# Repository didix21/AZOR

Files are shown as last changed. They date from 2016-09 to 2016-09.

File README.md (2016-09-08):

# AZOR
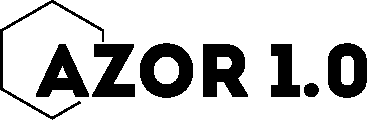
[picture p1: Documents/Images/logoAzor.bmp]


This repository contains all the AZOR 1.0 board KiCad files.  

## About Hardware 

AZOR 1.0 is based on [DUET 0.85](http://reprap.org/wiki/Duet#Drive_numbers) created by [dc42](https://github.com/dc42). I have done very important modifications as delete Ethernet and micro SD ports. Instead, I have added a USB 2.0 port to read USB Sticks. 

Moreover, the integrated steppers A4982 have been deleted and instead of that, I have placed HEADER PINS to connect drivers as A4988 or DRV8825. 

## About Software 

AZOR 1.0 use [Marlin4AZOR](https://github.com/didix21/Marlin4AZOR), it is a modified version of work  done by [Wurstnase](https://github.com/Wurstnase). In other words it is based on [Marlin4Due](https://github.com/Wurstnase/Marlin4Due).

## Main Features

- MCU: 32-bits, ATSAM3X8E-AU.
- Port Expansion
- Support for drivers: A4982 and DRV8825.
- Two FAN PWM ports.
- PTS-Panel Header Pin port.
- SD Header Pin Port.
- USB 2.0 port.

## License

Marlin is published under the [GPL license](LICENSE).

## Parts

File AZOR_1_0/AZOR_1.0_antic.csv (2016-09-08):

Id | Designator | Package | Quantity | Designation | Supplier and ref | Description
1 | U8,U11,U6,U5,U7 | DRV8825 | 10 | DRV8825_ | SSW-108-01-G-S | 2.54mm 8 Way 1 Row Straight PCB Socket Through Hole Board to Board
2 | U1 | LQFP144 | 1 | ATSAM3X8E | Atmel: ATSAM3X8EA-AU | Atmel ATSAM3X8EA-AU, 32bit ARM Cortex M3 Microcontroller, 84MHz, 16 kB, 2 x 256 kB Flash, ROM, 144-Pin LQFP
3 | TR3,TR1,TR7,TR6 | SOT-23 | 4 | BSH105 | BSH105,215 | NXP BSH105,215 N-channel MOSFET Transistor, 1.05 A, 20 V, 3-Pin TO-236AB
4 | C61,C68,C66,C59 | C_0805 | 4 | 4u7 | C0805C475K9PACTU | Kemet 0805 4.7?F Ceramic Multilayer Capacitor, 6.3V dc, 85°C, X5R Dielectric, ±10% SMD
5 | J22 | uUSB_new | 1 | USB | DX4R005H91 | SMT Type B Version 2.0 Micro USB Connector Socket, 100 V ac, 1.8A
6 | J23 | TERM_2-WAY_6.35mm | 1 | POWER IN | 1714955 | MKDS 5/2-6,35 2way 6.35mm terminal block
7 | TR5,TR9 | SOT-23 | 2 | PMV40UN2 | PMV40UN,215 | NXP PMV40UN,215 N-channel MOSFET Transistor, 4.9 A, 30 V, 3-Pin TO-236AB
8 | U2 | SOT-223 | 1 | TC2117-3.3VDBTR | TC2117-3.3VDBTR | Microchip TC2117-3.3VDBTR, LDO Voltage Regulator, 800mA, 3.3 V ±0.5%, 2.7 ? 6 Vin, 3-Pin SOT-223
9 | C23,C33,C32,C22,C3,C92,C94,C99,C102,C113 | C_ELEC_6.3x7.7 | 10 | 100u | EEEFTH101XAP | 100?F 50 V dc Aluminium Electrolytic Capacitor D8, FT SMD Series 2000h 6.3 Dia. x 7.7mm
10 | R18,R22,R60,R79 | R_0603 | 4 | 470R | CR0603-JW-471ELF | Bourns CR0603 Series Thick Film Surface Mount Resistor 0603 Case 470? ±5% 0.1W ±200ppm/°C
11 | R20,R23,R97 | R_0603 | 3 | 220R | CRG0603F220R | Thick Film Surface Mount Fixed Resistor 0603 Case 220? ±1% 0.1W ±100ppm/°C
12 | R57,R56,R58,R59 | R_0603 | 4 | 100R | CR0603-FX-1000ELF | Thick Film Surface Mount Fixed Resistor 0603 Case 100? ±1% 0.1W ±100ppm/°C
13 | R1 | R_0603 | 1 | 3K3 | CR0603-FX-3301ELF | Thick Film Surface Mount Fixed Resistor 0603 Case 3.3k? ±1% 0.1W ±100ppm/°C
14 | R2,R3 | R_0603 | 2 | 39R 1% | ERJ3RED39R0V | Thick Film Surface Mount Resistor 0603 Case 39? ±0.5% 0.1W ±100ppm/°C
15 | R24,R81,R80,R99,R82 | R_0603 | 5 | 10K | CR0603-FX-1002ELF | CR0603-FX Series Thick Film Surface Mount Fixed Resistor 0603 Case 10k? ±1% 0.1W ±100ppm/°C
16 | R25,R77,R78 | R_0603 | 3 | 100k | CR0603-FX-1003HLF | CR0603-FX Series Thick Film Surface Mount Fixed Resistor 0603 Case 100k? ±1% 0.1W ±100ppm/°C
17 | C40,C41,C42,C43,C70,C46,C48,C49,C72,C71,C69,C50,C67,C51,C64,C62,C52,C60,C91,C93,C112,C5 | C_0603 | 22 | 0u1 | C0603C105K8PACTU | Kemet 0603 C 1uF Ceramic Multilayer Capacitor, 10 V dc, +85°C, X5R Dielectric, ±10%
18 | R38,R40,R28,R26,R89 | R_0603 | 5 | 10k | CR0603-FX-1002ELF | CR0603-FX Series Thick Film Surface Mount Fixed Resistor 0603 Case 10k? ±1% 0.1W ±100ppm/°C
19 | R48 | R_0603 | 1 | 6k8 | ERA3AEB682V | Panasonic ERA Series Thin Film Surface Mount Resistor 0603 Case 6.8k? ±0.1% 0.1W ±25ppm/°C
20 | D3 | D_0603 | 1 | USB | LA L296-P2R1-1 | Opto LO L296-P2R1-24 Orange LED, 606 nm 0603, Rectangle Lens SMD Package
21 | C4,C18,C19,C47,C98,C97,C53 | C_0805 | 7 | 10u | C0805C106K4PACTU | Kemet 0805 C 10?F Ceramic Multilayer Capacitor, 16 V dc, +85°C, X5R Dielectric, ±10%
22 | TR4,TR2,TR8 | D-PAK | 3 | IPD036N04L | IPD036N04LG | Infineon IPD036N04LG N-channel MOSFET Transistor, 90 A, 40 V, 3-Pin TO-252
23 | R67,R68,R65,R55,R100,R98 | R_0603 | 6 | 4k7 | CR0603-FX-1000ELF | Bourns CR0603-FX Series Thick Film Surface Mount Fixed Resistor 0603 Case 100? ±1% 0.1W ±100ppm/°C
24 | D8 | D_0603 | 1 | FAN0 | LA L296-P2R1-1 | Opto LO L296-P2R1-24 Orange LED, 606 nm 0603, Rectangle Lens SMD Package
25 | D7 | D_0603 | 1 | E0 Heat | LP L296-J2L2-25 | Osram Opto LP L296-J2L2-25 Green LED, 560 nm 0603, Rectangle Lens SMD Package
26 | D6 | D_0603 | 1 | Bed Heat | LP L296-J2L2-25 | Osram Opto LP L296-J2L2-25 Green LED, 560 nm 0603, Rectangle Lens SMD Package
27 | J5 | PIN_ARRAY_2X1 | 1 | BED TEMP | 790-1098 | 2 way PCB terminal block 2.54mm
28 | R69,R70,R72 | R_0603 | 3 | 680R | CRCW0603680RFKEA | Vishay CRCW Series Thick Film Surface Mount Resistor 0603 Case 680? ±1% 0.1W ±100ppm/°C
29 | D9 | D_0603 | 1 | Y Stop | LO L296-P2R1-24 | Opto LO L296-P2R1-24 Orange LED, 606 nm 0603, Rectangle Lens SMD Package
30 | D10 | D_0603 | 1 | Z Stop | LO L296-P2R1-24 | Opto LO L296-P2R1-24 Orange LED, 606 nm 0603, Rectangle Lens SMD Package
31 | D12 | D_0603 | 1 | X Stop | LO L296-P2R1-24 | Opto LO L296-P2R1-24 Orange LED, 606 nm 0603, Rectangle Lens SMD Package
32 | D13,D14 | uSMA | 2 | SS14M | SS14 | Fairchild SS14, SMT Schottky Diode, 40V 1A, 2-Pin DO-214AC
33 | R21,R19,R53 | R_0603 | 3 | 4K7 | CR0603-FX-1000ELF | Bourns CR0603-FX Series Thick Film Surface Mount Fixed Resistor 0603 Case 100? ±1% 0.1W ±100ppm/°C
34 | L6,L5,L4,L3,L7 | R_0603 | 5 | 100Mhz | 3613C1R0K | Series Shielded Wire-wound SMD Inductor with a Ferrite Core, 1uH ±10% 450mA
35 | C13,C95 | C_0603 | 2 | 1u | C0603C105K4PACTU | Kemet 0603 C 1?F Ceramic Multilayer Capacitor, 16 V dc, +85°C, X5R Dielectric, ±10%
36 | C44,C45,C65 | C_0603 | 3 | 10p | C0603C100J5GACTU | Kemet 0603 10pF Ceramic Multilayer Capacitor, 50V dc, 125°C, C0G Dielectric, ±5% SMD
37 | C2 | C_0603 | 1 | 0u01 | C0603C100J5GACTU | Kemet 0603 10pF Ceramic Multilayer Capacitor, 50V dc, 125°C, C0G Dielectric, ±5% SMD
38 | R54 | R_0603 | 1 | 2k7 | CR0603-FX-1000ELF | Bourns CR0603-FX Series Thick Film Surface Mount Fixed Resistor 0603 Case 100? ±1% 0.1W ±100ppm/°C
39 | R61 | R_0603 | 1 | 2K15 | CRCW06032K15FKEA | Vishay CRCW Series Thick Film Surface Mount Resistor 0603 Case 2.15k? ±1% 0.1W ±100ppm/°C
40 | D1,D2 | DO-220AA | 2 | SS3P4 | SS3P4-M3/84A | Vishay SS3P4-M3/84A, SMT Schottky Diode, 40V 3A, 2-Pin SMP
41 | X2 | Xtal_5x3.2 | 1 | CRYSTAL_4PIN |  | 12MHz KX-7 20pF, CRYSTAL -3.2-2.5
42 | JP9 | JUMPER | 1 | 5V_EN | W81102T3825RC | RS Pro, 2.54mm Pitch 2 Way 1 Row Straight PCB Header, Solder Termination
43 | JP10 | JUMPER | 1 | ATX_5V_EN | W81102T3825RC | RS Pro, 2.54mm Pitch 2 Way 1 Row Straight PCB Header, Solder Termination
44 | J27,J26 | TP | 2 | GND | 68000-401HLF | Amphenol FCI BergStik Series, Series Number 68000, 2.54mm Pitch 1 Way 1 Row Straight Header, Through Hole Termination
45 | D16 | D_0603 | 1 | 3.3V | LP L296-J2L2-25 | Osram Opto LP L296-J2L2-25 Green LED, 560 nm 0603, Rectangle Lens SMD Package
46 | D17 | D_0603 | 1 | 5V+ | LP L296-J2L2-25 | Osram Opto LP L296-J2L2-25 Green LED, 560 nm 0603, Rectangle Lens SMD Package
47 | D15 | D_0603 | 1 | VIN | LP L296-J2L2-25 | Osram Opto LP L296-J2L2-25 Green LED, 560 nm 0603, Rectangle Lens SMD Package
48 | C90 | C_0603 | 1 | 10nF | C0603C103K5RACTU | Kemet 0603 10nF Ceramic Multilayer Capacitor, 50V dc, 125°C, X7R Dielectric, ±10% SMD
49 | J4 | TERM_2-WAY_6.35mm | 1 | BED HEAT | 1714955 | MKDS 5/2-6,35 2way 6.35mm terminal block
50 | ,, | Fixing_M3 | 3
51 | R86,R85 | R_1206 | 2 | 0R1 | ERJ8BWFR100V | Panasonic ERJ8BW Series Thick Film Low Ohmic Surface Mount Resistor 1206 Case 100m? ±1% 1W ±100ppm/°C
52 | R88 | R_0603 | 1 | 750R | CRCW0603750RFKEA | Vishay CRCW Series Thick Film Surface Mount Resistor 0603 Case 750? ±1% 0.1W ±100ppm/°C
53 | R87 | R_0603 | 1 | 3K92 | ERA3ARB3921V | Panasonic Thin Film Surface Mount Resistor 0603 Case 3.92k? ±0.1% 0.1W ±10ppm/°C
54 | R84 | R_0603 | 1 | 100K | CRG0603F100K | TE Connectivity CRG0603 Series Thick Film Surface Mount Resistor 0603 Case 100k? ±1% 0.1W ±100ppm/°C
55 | J30 | PIN_ARRAY_4x1 | 1 | PanelDUE | W81136T3825RC | RS Pro W81136 Series, 2.54mm Pitch 36 Way 1 Row Straight PCB Header, Solder Termination, 4A
56 | J29 | PIN_ARRAY_2X1 | 1 | FAN 1 | W81102T3825RC | RS Pro, 2.54mm Pitch 2 Way 1 Row Straight PCB Header, Solder Termination
57 | J25 | PIN_ARRAY_2X1 | 1 | FAN 0 | W81102T3825RC | RS Pro, 2.54mm Pitch 2 Way 1 Row Straight PCB Header, Solder Termination
58 | J12 | PIN_ARRAY_2X1 | 1 | E0 TEMP | W81102T3825RC | RS Pro, 2.54mm Pitch 2 Way 1 Row Straight PCB Header, Solder Termination
59 | J13 | PHOENIX_CONNECTOR_2 | 1 | E1 HEAT | 1751248 | Phoenix Contact COMBICON MKDS Series 3,5mm Pitch Straight PCB Terminal Block with Screw Termination
60 | J14 | PIN_ARRAY_2X1 | 1 | E1 TEMP | W81102T3825RC | RS Pro, 2.54mm Pitch 2 Way 1 Row Straight PCB Header, Solder Termination
61 | D20 | D_0603 | 1 | E1 Heat | LP L296-J2L2-25 | Osram Opto LP L296-J2L2-25 Green LED, 560 nm 0603, Rectangle Lens SMD Package
62 | D21 | D_0603 | 1 | FAN1 | LO L296-P2R1-24 | Opto LO L296-P2R1-24 Orange LED, 606 nm 0603, Rectangle Lens SMD Package
63 | C96 | C_0603 | 1 | 22nF | C0603C223K5RACTU | Kemet 0603 22nF Ceramic Multilayer Capacitor, 50V dc, 125°C, X7R Dielectric, ±10% SMD
64 | C1 | C_0603 | 1 | 2u2 | C0603C225K4PACTU | Kemet 0603 C 2.2?F Ceramic Multilayer Capacitor, 16 V dc, +85°C, X5R Dielectric, ±10%
65 | U3 | QFN16-4x4 | 1 | A4403 | A4403GEUTR-T | Allegro Microsystems, A4403GEUTR-T Step-Down Switching Regulator 3A, 16-Pin QFN
66 | S1 | SW_SIDE_1 | 1 | RESET | http://www.shoptronica.com/pulsadores-smd/2115-pulsador-tact-switch-lateral-smd-45x54x16mm.html | Button Pulser Tact Switch 4.5x4.5x1.6 mm SMD 90º
67 | L1 | L_6x6 | 1 | 10uH | SD54-103MLB | SMD inductor 10uH 6x5mm
68 | J11 | PHOENIX_CONNECTOR_2 | 1 | E0 HEAT | 1751248 | Phoenix Contact COMBICON MKDS Series 3,5mm Pitch Straight PCB Terminal Block with Screw Termination
69 | S2 | SW_SIDE_1 | 1 | ERASE | http://www.shoptronica.com/pulsadores-smd/2115-pulsador-tact-switch-lateral-smd-45x54x16mm.html | Button Pulser Tact Switch 4.5x4.5x1.6 mm SMD 90º
70 | Fid,Fid,Fid,Fid | Fiducial | 4 | VAL**
71 | P1 | USB_A | 1 | USB-A-PCB | 292303-7 | TE Connectivity Right Angle Version 2.0 Type A USB Connector, PCB Mount Socket
72 | J1 | PIN_ARRAY_18X2 | 1 | CONN2X18 | 87606-318LF | Amphenol FCI 2.54mm 36 Way 2 Row Straight PCB Socket Through Hole Board to Board
73 | J15 | PIN_ARRAY_4x1 | 1 | Z MOT | W81136T3825RC | RS Pro W81136 Series, 2.54mm Pitch 36 Way 1 Row Straight PCB Header, Solder Termination, 4A
74 | J7 | PIN_ARRAY_7X1 | 1 | Z MOT/STOP | TSW-107-07-L-S | Samtec TSW Series, 2.54mm Pitch 7 Way 1 Row Straight PCB Header, Solder Termination, 7.6A
75 | J8 | PIN_ARRAY_7X1 | 1 | Y MOT/STOP | TSW-107-07-L-S | Samtec TSW Series, 2.54mm Pitch 7 Way 1 Row Straight PCB Header, Solder Termination, 7.6A
76 | J9 | PIN_ARRAY_7X1 | 1 | X MOT/STOP | TSW-107-07-L-S | Samtec TSW Series, 2.54mm Pitch 7 Way 1 Row Straight PCB Header, Solder Termination, 7.6A
77 | J10 | PIN_ARRAY_4x1 | 1 | E0 MOT | W81136T3825RC | RS Pro W81136 Series, 2.54mm Pitch 36 Way 1 Row Straight PCB Header, Solder Termination, 4A
78 | J6 | PIN_ARRAY_4x1 | 1 | E1 MOT | W81136T3825RC | RS Pro W81136 Series, 2.54mm Pitch 36 Way 1 Row Straight PCB Header, Solder Termination, 4A
79 | G*** | LOGO | 1 | LOGO

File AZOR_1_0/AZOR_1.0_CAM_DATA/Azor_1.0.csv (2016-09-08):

Id | Designator | Package | Quantity | Designation | Supplier and ref | Description
1 | TR4,TR2,TR8 | D-PAK | 3 | IPD036N04L | IPD036N04LG | Infineon IPD036N04LG N-channel MOSFET Transistor, 90 A, 40 V, 3-Pin TO-252
2 | J11 | PHOENIX_CONNECTOR_2 | 1 | E0 HEAT | 1751248 | Phoenix Contact COMBICON MKDS Series 3,5mm Pitch Straight PCB Terminal Block with Screw Termination
3 | J25 | PIN_ARRAY_2X1 | 1 | FAN 0 | W81102T3825RC | RS Pro, 2.54mm Pitch 2 Way 1 Row Straight PCB Header, Solder Termination
4 | TR5,TR9 | SOT-23 | 2 | PMV40UN2 | PMV40UN,215 | NXP PMV40UN,215 N-channel MOSFET Transistor, 4.9 A, 30 V, 3-Pin TO-236AB
5 | D20 | D_0603 | 1 | E1 Heat | LP L296-J2L2-25 | Osram Opto LP L296-J2L2-25 Green LED, 560 nm 0603, Rectangle Lens SMD Package
6 | J22 | uUSB_new | 1 | Micro USB | DX4R005H91 | SMT Type B Version 2.0 Micro USB Connector Socket, 100 V ac, 1.8A
7 | L1 | L_6x6 | 1 | 10uH | SD54-103MLB | SMD inductor 10uH 6x5mm
8 | U8,U11,U6,U5,U7 | DRV8825 | 5 | DRV8825_ | SSW-108-01-G-S | 2.54mm 8 Way 1 Row Straight PCB Socket Through Hole Board to Board
9 | U1 | LQFP144 | 1 | ATSAM3X8E | Atmel: ATSAM3X8EA-AU | Atmel ATSAM3X8EA-AU, 32bit ARM Cortex M3 Microcontroller, 84MHz, 16 kB, 2 x 256 kB Flash, ROM, 144-Pin LQFP
10 | TR3,TR1,TR6 | SOT-23 | 3 | BSH105 | BSH105,215 | NXP BSH105,215 N-channel MOSFET Transistor, 1.05 A, 20 V, 3-Pin TO-236AB
11 | C61,C68,C66,C59 | C_0805 | 4 | 4u7 | C0805C475K9PACTU | Kemet 0805 4.7?F Ceramic Multilayer Capacitor, 6.3V dc, 85°C, X5R Dielectric, ±10% SMD
12 | J23 | TERM_2-WAY_6.35mm | 1 | POWER IN | 1714955 | MKDS 5/2-6,35 2way 6.35mm terminal block
13 | U2 | SOT-223 | 1 | TC2117-3.3VDBTR | TC2117-3.3VDBTR | Microchip TC2117-3.3VDBTR, LDO Voltage Regulator, 800mA, 3.3 V ±0.5%, 2.7 ? 6 Vin, 3-Pin SOT-223
14 | C23,C33,C32,C22,C3,C92,C94,C99,C102,C113 | C_ELEC_6.3x7.7 | 10 | 100u | EEEFTH101XAP | 100?F 50 V dc Aluminium Electrolytic Capacitor D8, FT SMD Series 2000h 6.3 Dia. x 7.7mm
15 | R18,R22,R60,R79 | R_0603 | 4 | 470R | CR0603-JW-471ELF | Bourns CR0603 Series Thick Film Surface Mount Resistor 0603 Case 470? ±5% 0.1W ±200ppm/°C
16 | R20,R23,R97 | R_0603 | 3 | 220R | CRG0603F220R | Thick Film Surface Mount Fixed Resistor 0603 Case 220? ±1% 0.1W ±100ppm/°C
17 | R57,R56,R58,R59 | R_0603 | 4 | 100R | CR0603-FX-1000ELF | Thick Film Surface Mount Fixed Resistor 0603 Case 100? ±1% 0.1W ±100ppm/°C
18 | R1 | R_0603 | 1 | 3K3 | CR0603-FX-3301ELF | Thick Film Surface Mount Fixed Resistor 0603 Case 3.3k? ±1% 0.1W ±100ppm/°C
19 | R2,R3 | R_0603 | 2 | 39R 1% | ERJ3RED39R0V | Thick Film Surface Mount Resistor 0603 Case 39? ±0.5% 0.1W ±100ppm/°C
20 | R24,R81,R80,R99,R82,R103 | R_0603 | 6 | 10K | CR0603-FX-1002ELF | CR0603-FX Series Thick Film Surface Mount Fixed Resistor 0603 Case 10k? ±1% 0.1W ±100ppm/°C
21 | R25,R77,R78 | R_0603 | 3 | 100k | CR0603-FX-1003HLF | CR0603-FX Series Thick Film Surface Mount Fixed Resistor 0603 Case 100k? ±1% 0.1W ±100ppm/°C
22 | C40,C41,C42,C43,C70,C46,C48,C49,C72,C71,C69,C50,C67,C51,C64,C62,C52,C60,C91,C93,C112,C5 | C_0603 | 22 | 0u1 | C0603C105K8PACTU | Kemet 0603 C 1uF Ceramic Multilayer Capacitor, 10 V dc, +85°C, X5R Dielectric, ±10%
23 | R38,R40,R28,R26,R89 | R_0603 | 5 | 10k | CR0603-FX-1002ELF | CR0603-FX Series Thick Film Surface Mount Fixed Resistor 0603 Case 10k? ±1% 0.1W ±100ppm/°C
24 | R48 | R_0603 | 1 | 6k8 | ERA3AEB682V | Panasonic ERA Series Thin Film Surface Mount Resistor 0603 Case 6.8k? ±0.1% 0.1W ±25ppm/°C
25 | D3 | D_0603 | 1 | USB | LA L296-P2R1-1 | Opto LO L296-P2R1-24 Orange LED, 606 nm 0603, Rectangle Lens SMD Package
26 | C4,C18,C19,C47,C98,C97,C53 | C_0805 | 7 | 10u | C0805C106K4PACTU | Kemet 0805 C 10?F Ceramic Multilayer Capacitor, 16 V dc, +85°C, X5R Dielectric, ±10%
27 | R67,R68,R65,R55,R100,R98 | R_0603 | 6 | 4k7 | CR0603-FX-1000ELF | Bourns CR0603-FX Series Thick Film Surface Mount Fixed Resistor 0603 Case 100? ±1% 0.1W ±100ppm/°C
28 | D8 | D_0603 | 1 | FAN0 | LA L296-P2R1-1 | Opto LO L296-P2R1-24 Orange LED, 606 nm 0603, Rectangle Lens SMD Package
29 | D7 | D_0603 | 1 | E0 Heat | LP L296-J2L2-25 | Osram Opto LP L296-J2L2-25 Green LED, 560 nm 0603, Rectangle Lens SMD Package
30 | D6 | D_0603 | 1 | Bed Heat | LP L296-J2L2-25 | Osram Opto LP L296-J2L2-25 Green LED, 560 nm 0603, Rectangle Lens SMD Package
31 | J5 | PIN_ARRAY_2X1 | 1 | BED TEMP | 790-1098 | 2 way PCB terminal block 2.54mm
32 | R69,R70,R72 | R_0603 | 3 | 680R | CRCW0603680RFKEA | Vishay CRCW Series Thick Film Surface Mount Resistor 0603 Case 680? ±1% 0.1W ±100ppm/°C
33 | D9 | D_0603 | 1 | Y Stop | LO L296-P2R1-24 | Opto LO L296-P2R1-24 Orange LED, 606 nm 0603, Rectangle Lens SMD Package
34 | D10 | D_0603 | 1 | Z Stop | LO L296-P2R1-24 | Opto LO L296-P2R1-24 Orange LED, 606 nm 0603, Rectangle Lens SMD Package
35 | D12 | D_0603 | 1 | X Stop | LO L296-P2R1-24 | Opto LO L296-P2R1-24 Orange LED, 606 nm 0603, Rectangle Lens SMD Package
36 | D13 | uSMA | 1 | SS14M | SS14 | Fairchild SS14, SMT Schottky Diode, 40V 1A, 2-Pin DO-214AC
37 | R21,R19,R53 | R_0603 | 3 | 4K7 | CR0603-FX-1000ELF | Bourns CR0603-FX Series Thick Film Surface Mount Fixed Resistor 0603 Case 100? ±1% 0.1W ±100ppm/°C
38 | L6,L5,L4,L3,L7 | R_0603 | 5 | 100Mhz | 3613C1R0K | Series Shielded Wire-wound SMD Inductor with a Ferrite Core, 1uH ±10% 450mA
39 | C13,C95 | C_0603 | 2 | 1u | C0603C105K4PACTU | Kemet 0603 C 1?F Ceramic Multilayer Capacitor, 16 V dc, +85°C, X5R Dielectric, ±10%
40 | C44,C45,C65 | C_0603 | 3 | 10p | C0603C100J5GACTU | Kemet 0603 10pF Ceramic Multilayer Capacitor, 50V dc, 125°C, C0G Dielectric, ±5% SMD
41 | C2 | C_0603 | 1 | 0u01 | C0603C100J5GACTU | Kemet 0603 10pF Ceramic Multilayer Capacitor, 50V dc, 125°C, C0G Dielectric, ±5% SMD
42 | R61 | R_0603 | 1 | 2K15 | CRCW06032K15FKEA | Vishay CRCW Series Thick Film Surface Mount Resistor 0603 Case 2.15k? ±1% 0.1W ±100ppm/°C
43 | D1,D2 | DO-220AA | 2 | SS3P4 | SS3P4-M3/84A | Vishay SS3P4-M3/84A, SMT Schottky Diode, 40V 3A, 2-Pin SMP
44 | JP9 | JUMPER | 1 | 5V_EN | W81102T3825RC | RS Pro, 2.54mm Pitch 2 Way 1 Row Straight PCB Header, Solder Termination
45 | J27,J26 | TP | 2 | GND | 68000-401HLF | Amphenol FCI BergStik Series, Series Number 68000, 2.54mm Pitch 1 Way 1 Row Straight Header, Through Hole Termination
46 | D16 | D_0603 | 1 | 3.3V | LB Q39G-L2OO-35-1 | Osram Opto LB Q39G-L2OO-35-1 Blue LED, 476 nm 0603 Diffused, Rectangle Lens SMD package
47 | D17 | D_0603 | 1 | 5V+ | LB Q39G-L2OO-35-1 | Osram Opto LB Q39G-L2OO-35-1 Blue LED, 476 nm 0603 Diffused, Rectangle Lens SMD package
48 | D15 | D_0603 | 1 | VIN | LB Q39G-L2OO-35-1 | Osram Opto LB Q39G-L2OO-35-1 Blue LED, 476 nm 0603 Diffused, Rectangle Lens SMD package
49 | C90 | C_0603 | 1 | 10nF | C0603C103K5RACTU | Kemet 0603 10nF Ceramic Multilayer Capacitor, 50V dc, 125°C, X7R Dielectric, ±10% SMD
50 | J4 | TERM_2-WAY_6.35mm | 1 | BED HEAT | 1714955 | MKDS 5/2-6,35 2way 6.35mm terminal block
51 | ,, | Fixing_M3 | 3
52 | R86,R85 | R_1206 | 2 | 0R1 | ERJ8BWFR100V | Panasonic ERJ8BW Series Thick Film Low Ohmic Surface Mount Resistor 1206 Case 100m? ±1% 1W ±100ppm/°C
53 | R88 | R_0603 | 1 | 750R | CRCW0603750RFKEA | Vishay CRCW Series Thick Film Surface Mount Resistor 0603 Case 750? ±1% 0.1W ±100ppm/°C
54 | R87 | R_0603 | 1 | 3K92 | ERA3ARB3921V | Panasonic Thin Film Surface Mount Resistor 0603 Case 3.92k? ±0.1% 0.1W ±10ppm/°C
55 | R84 | R_0603 | 1 | 100K | CRG0603F100K | TE Connectivity CRG0603 Series Thick Film Surface Mount Resistor 0603 Case 100k? ±1% 0.1W ±100ppm/°C
56 | J30 | Molex_KK-6410-04_04x2,54mm_Straight | 1 | PanelDUE | 22-27-2041 | Molex KK 254 Series, Series Number 6410, 2.54mm Pitch 4 Way 1 Row Straight PCB Header, Solder Termination, 4A Termination, 4A
57 | J29 | PIN_ARRAY_2X1 | 1 | FAN 1 | W81102T3825RC | RS Pro, 2.54mm Pitch 2 Way 1 Row Straight PCB Header, Solder Termination
58 | J12 | PIN_ARRAY_2X1 | 1 | E0 TEMP | W81102T3825RC | RS Pro, 2.54mm Pitch 2 Way 1 Row Straight PCB Header, Solder Termination
59 | J14 | PIN_ARRAY_2X1 | 1 | E1 TEMP | W81102T3825RC | RS Pro, 2.54mm Pitch 2 Way 1 Row Straight PCB Header, Solder Termination
60 | D21 | D_0603 | 1 | FAN1 | LO L296-P2R1-24 | Opto LO L296-P2R1-24 Orange LED, 606 nm 0603, Rectangle Lens SMD Package
61 | C96 | C_0603 | 1 | 22nF | C0603C223K5RACTU | Kemet 0603 22nF Ceramic Multilayer Capacitor, 50V dc, 125°C, X7R Dielectric, ±10% SMD
62 | C1 | C_0603 | 1 | 2u2 | C0603C225K4PACTU | Kemet 0603 C 2.2?F Ceramic Multilayer Capacitor, 16 V dc, +85°C, X5R Dielectric, ±10%
63 | U3 | QFN16-4x4 | 1 | A4403 | A4403GEUTR-T | Allegro Microsystems, A4403GEUTR-T Step-Down Switching Regulator 3A, 16-Pin QFN
64 | Fid,Fid,Fid,Fid | Fiducial | 4 | VAL**
65 | P1 | USB_A | 1 | USB-A-PCB | 292303-7 | TE Connectivity Right Angle Version 2.0 Type A USB Connector, PCB Mount Socket
66 | J1 | PIN_ARRAY_18X2 | 1 | CONN2X18 | 87606-318LF | Amphenol FCI 2.54mm 36 Way 2 Row Straight PCB Socket Through Hole Board to Board
67 | J15 | PIN_ARRAY_4x1 | 1 | Z MOT | W81136T3825RC | RS Pro W81136 Series, 2.54mm Pitch 36 Way 1 Row Straight PCB Header, Solder Termination, 4A
68 | J7 | PIN_ARRAY_7X1 | 1 | Z MOT/STOP | TSW-107-07-L-S | Samtec TSW Series, 2.54mm Pitch 7 Way 1 Row Straight PCB Header, Solder Termination, 7.6A
69 | J8 | PIN_ARRAY_7X1 | 1 | Y MOT/STOP | TSW-107-07-L-S | Samtec TSW Series, 2.54mm Pitch 7 Way 1 Row Straight PCB Header, Solder Termination, 7.6A
70 | J9 | PIN_ARRAY_7X1 | 1 | X MOT/STOP | TSW-107-07-L-S | Samtec TSW Series, 2.54mm Pitch 7 Way 1 Row Straight PCB Header, Solder Termination, 7.6A
71 | J10 | PIN_ARRAY_4x1 | 1 | E0 MOT | W81136T3825RC | RS Pro W81136 Series, 2.54mm Pitch 36 Way 1 Row Straight PCB Header, Solder Termination, 4A
72 | J6 | PIN_ARRAY_4x1 | 1 | E1 MOT | W81136T3825RC | RS Pro W81136 Series, 2.54mm Pitch 36 Way 1 Row Straight PCB Header, Solder Termination, 4A
73 | J13 | PHOENIX_CONNECTOR_2 | 1 | E1 HEAT | 1751248 | Phoenix Contact COMBICON MKDS Series 3,5mm Pitch Straight PCB Terminal Block with Screw Termination
74 | S1 | SW_LITTLE_PCB_1 | 1 | RESET | http://www.shoptronica.com/pulsadores-smd/2115-pulsador-tact-switch-lateral-smd-45x54x16mm.html | Button Pulser Tact Switch 4.5x4.5x1.6 mm SMD 90º
75 | S2 | SW_LITTLE_PCB_1 | 1 | ERASE | http://www.shoptronica.com/pulsadores-smd/2115-pulsador-tact-switch-lateral-smd-45x54x16mm.html | Button Pulser Tact Switch 4.5x4.5x1.6 mm SMD 90º
76 | X2,X5 | CRYSTAL_KX_7_12MHz | 2 | CRYSTAL_4PIN | 12MHz KX-7 20pF, CRYSTAL -3.2-2.5
77 | J31 | Molex_KK-6410-05_05x2,54mm_Straight | 1 | SD_CON | 22-27-2051 | Molex KK 254 Series, Series Number 6410, 2.54mm Pitch 5 Way 1 Row Straight PCB Header, Solder Termination, 4A
78 | R101,R102 | R_0603 | 2 | 22R 1% | CRCW060322R0FKEAHP | Vishay CRCW Series Thick Film Power Resistor 0603 Case 22? ±1% 0.25W ±100ppm/K
79 | D50,D51 | CT/CN0603 | 2 | PGB1010604 |  | VARISTOR
80 | U10 | MAX3421EEHJ | 1 | MAX3421EEHJ |  | MAX3421 SPI to USB Interface Chip
81 | F1 | L_1812 | 1 | MF-MSMF050-2 500 mA |  | INDUCTOR, Europen Symbol
82 | L21,L20 | WE-CBF_0805 | 2 | BLM21 |  | SMD EMI Suppression Ferrite Beads
83 | C114,C118,C117 | C_0603 | 3 | 100n | C0603C104K4RACTU | Kemet 0603 0.1?F Ceramic Multilayer Capacitor, 16V dc, 125°C, X7R Dielectric, ±10% SMD
84 | C115,C116 | C_0603 | 2 | 22p | C0603C220J5GACTU | Kemet 0603 22pF Ceramic Multilayer Capacitor, 50V dc, 125°C, C0G Dielectric, ±5% SMD

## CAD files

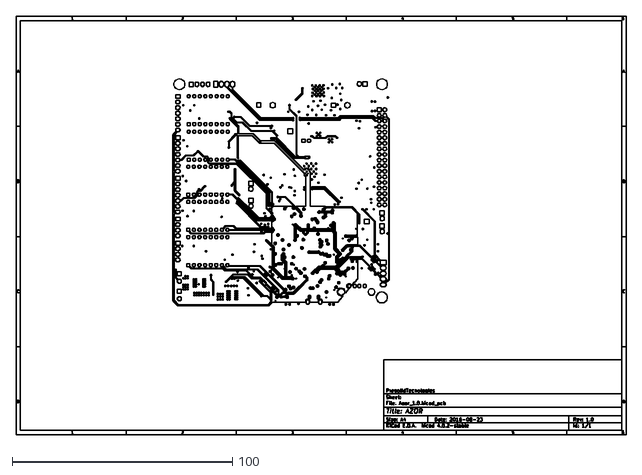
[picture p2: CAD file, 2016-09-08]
AZOR_1_0/AZOR_1.0_CAM_DATA/dxf/Azor_1.0-Inner3.dxf
277.0 x 190.0

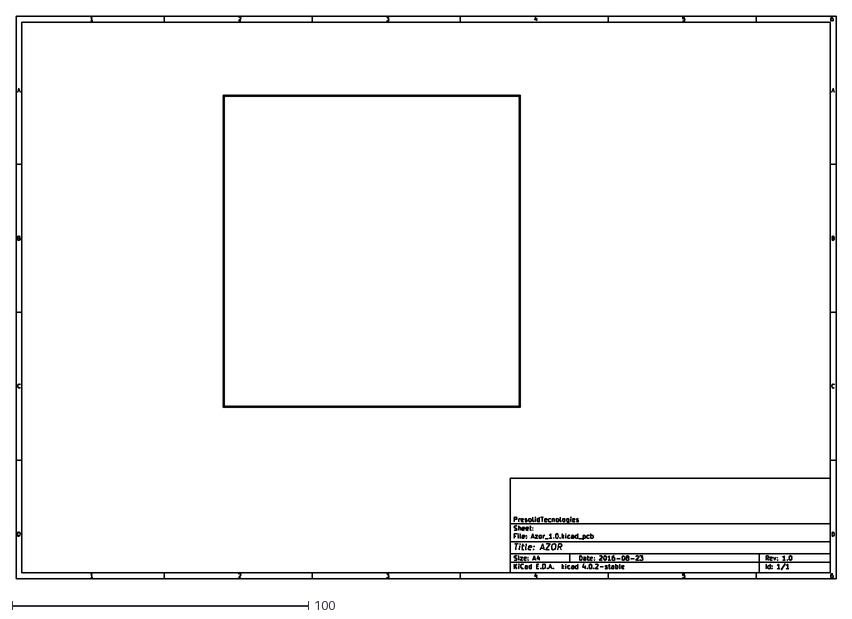
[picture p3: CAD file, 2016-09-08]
AZOR_1_0/AZOR_1.0_CAM_DATA/dxf/Azor_1.0-Edge.Cuts.dxf
277.0 x 190.0

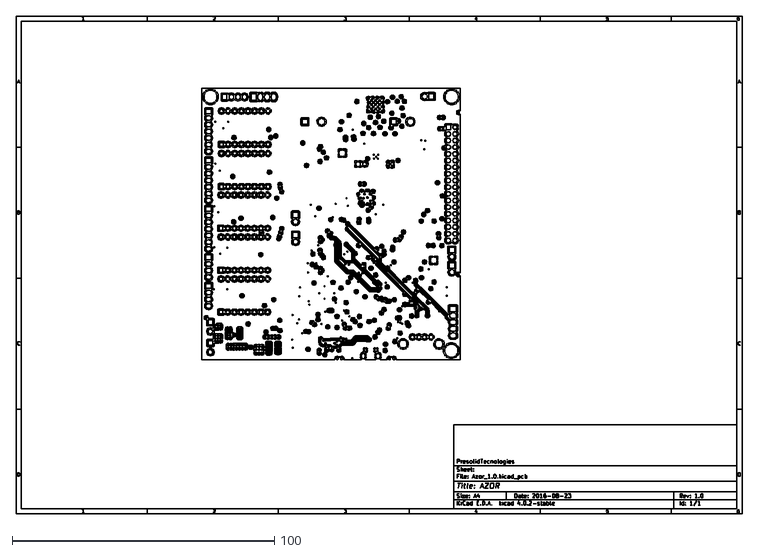
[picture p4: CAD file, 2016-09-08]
AZOR_1_0/AZOR_1.0_CAM_DATA/dxf/Azor_1.0-Inner2.dxf
277.0 x 190.0

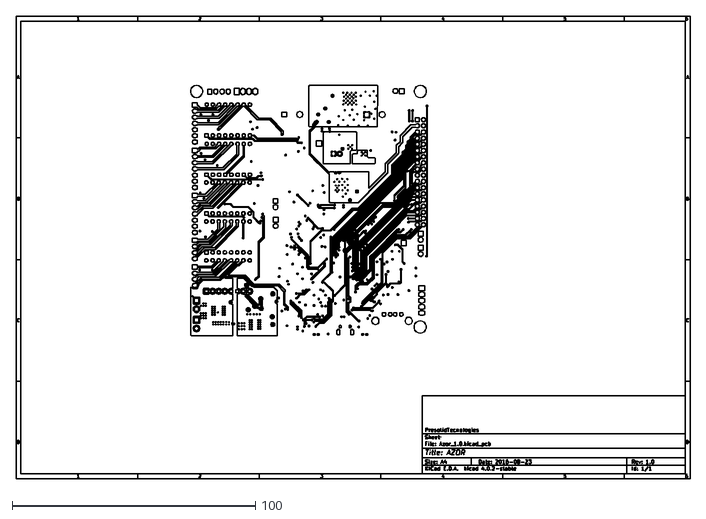
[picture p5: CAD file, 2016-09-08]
AZOR_1_0/AZOR_1.0_CAM_DATA/dxf/Azor_1.0-Back.dxf
277.0 x 190.0

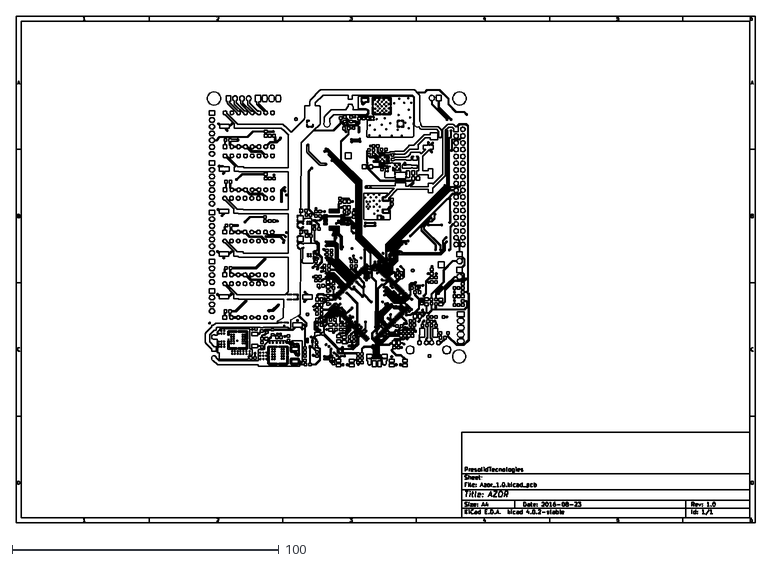
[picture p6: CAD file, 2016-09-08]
AZOR_1_0/AZOR_1.0_CAM_DATA/dxf/Azor_1.0-Front.dxf
277.0 x 190.0

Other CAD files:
AZOR_1_0/AZOR_1.0_CAM_DATA/dxf/Azor_1.0-B.Mask.dxf
AZOR_1_0/AZOR_1.0_CAM_DATA/dxf/Azor_1.0-B.SilkS.dxf
AZOR_1_0/AZOR_1.0_CAM_DATA/dxf/Azor_1.0-F.Mask.dxf
AZOR_1_0/AZOR_1.0_CAM_DATA/dxf/Azor_1.0-F.Paste.dxf
AZOR_1_0/AZOR_1.0_CAM_DATA/dxf/Azor_1.0-F.SilkS.dxf

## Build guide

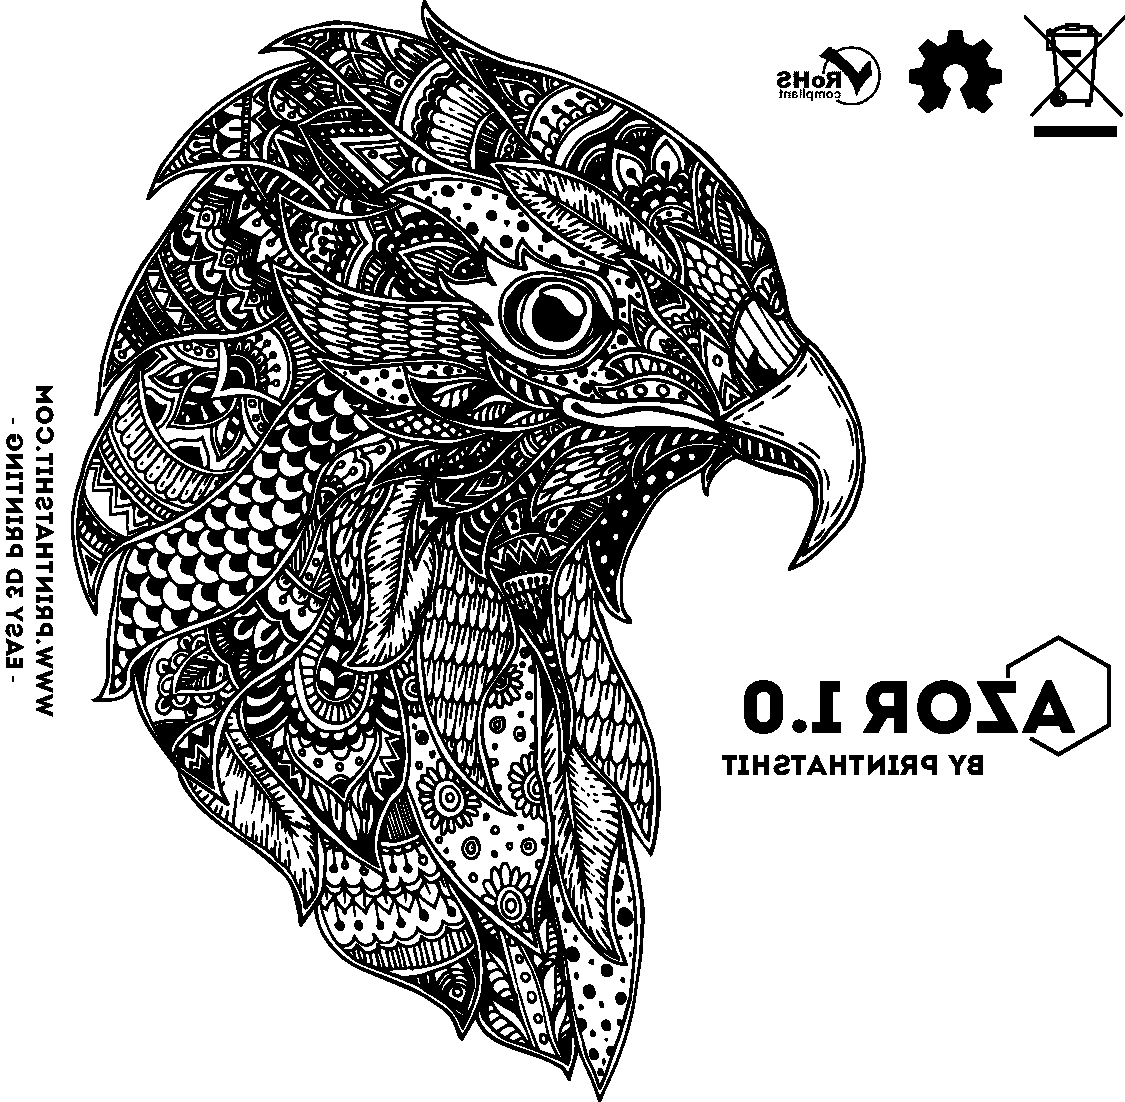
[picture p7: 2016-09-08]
Documents/Images/silkscreen-mirror-printer-electronics-105_100.BMP

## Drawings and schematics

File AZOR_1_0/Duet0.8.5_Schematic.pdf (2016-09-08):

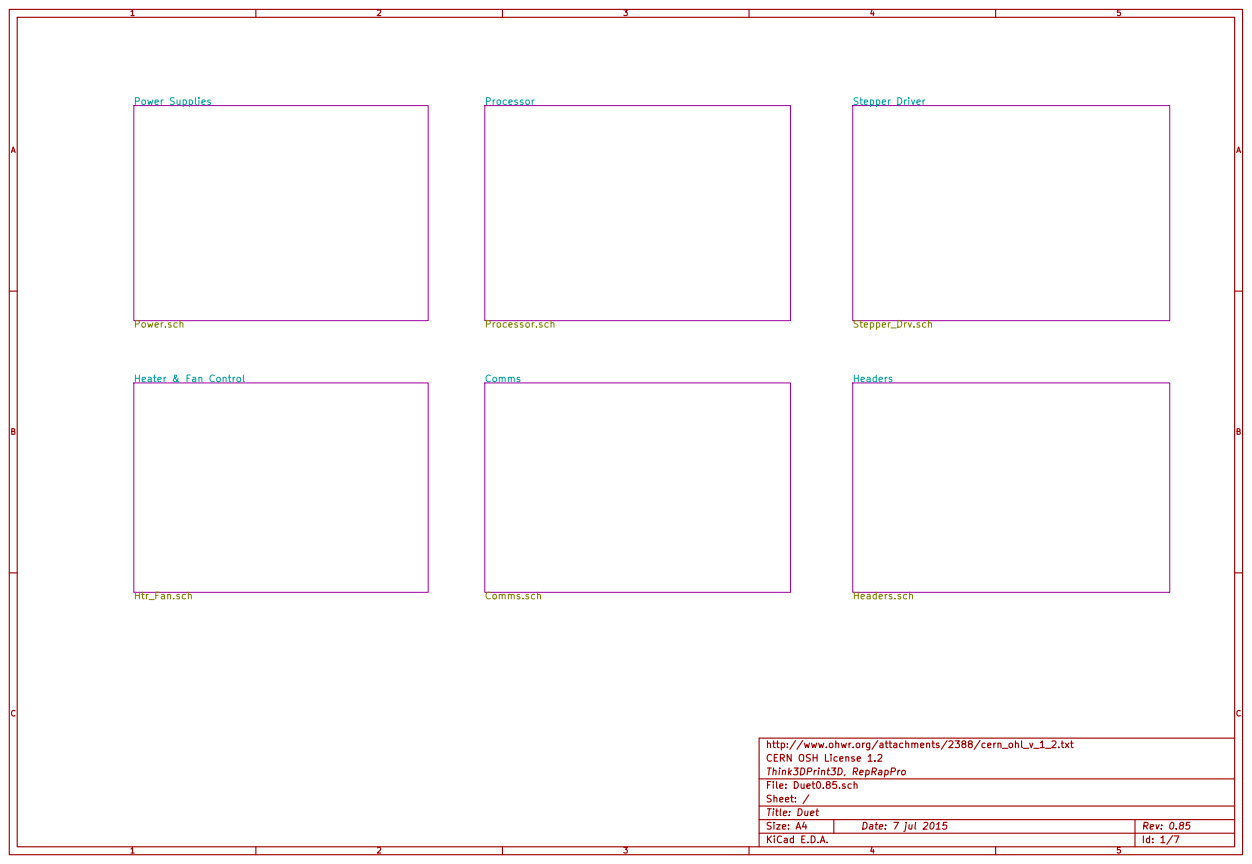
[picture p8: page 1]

http://www.ohwr.org/attachments/2388/cern_ohl_v_1_2.txt
CERN OSH License 1.2
Think3DPrint3D, RepRapPro
Id: 1/7 Title: Duet File: Duet0.85.sch Sheet: /

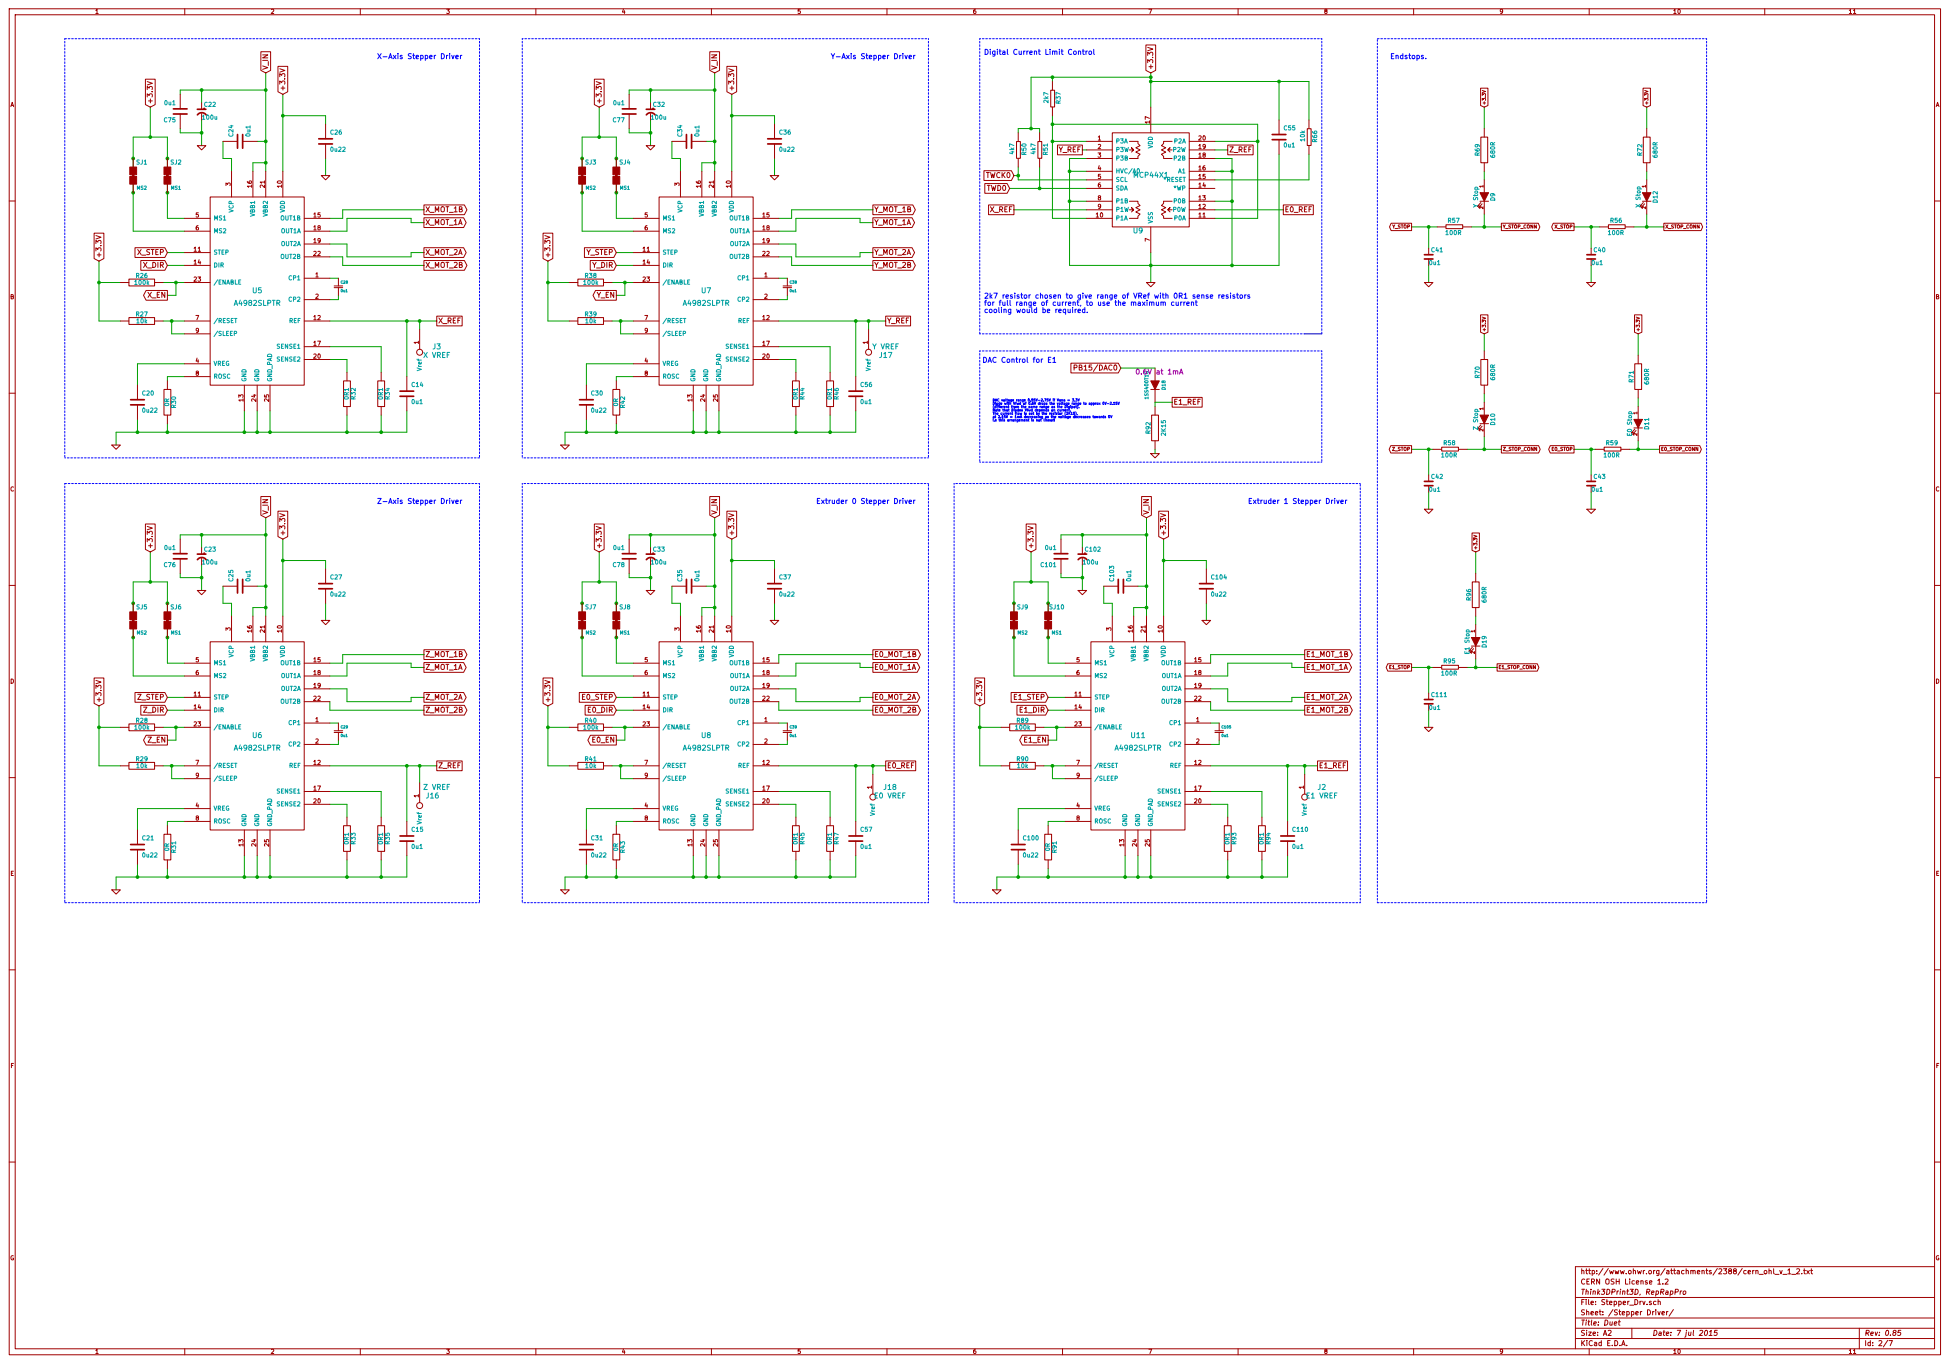
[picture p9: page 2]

Endstops. Digital Current Limit Control

for full range of current, to use the maximum current

DAC voltage range 0.55V-2.75V if Vana = 3.3V Diode with Vfwd of 0.6V drops the voltage range to approx 0V-2.15V
(different from the same range as the Digipot). Note that Diodes Vfwd depends on current. The current flow is set by the resistor (2K15), at 2.15V = 1mA decreasing as the voltage decreases towards 0V

http://www.ohwr.org/attachments/2388/cern_ohl_v_1_2.txt
CERN OSH License 1.2
Think3DPrint3D, RepRapPro
Id: 2/7 Title: Duet File: Stepper_Drv.sch
Sheet: /Stepper Driver/

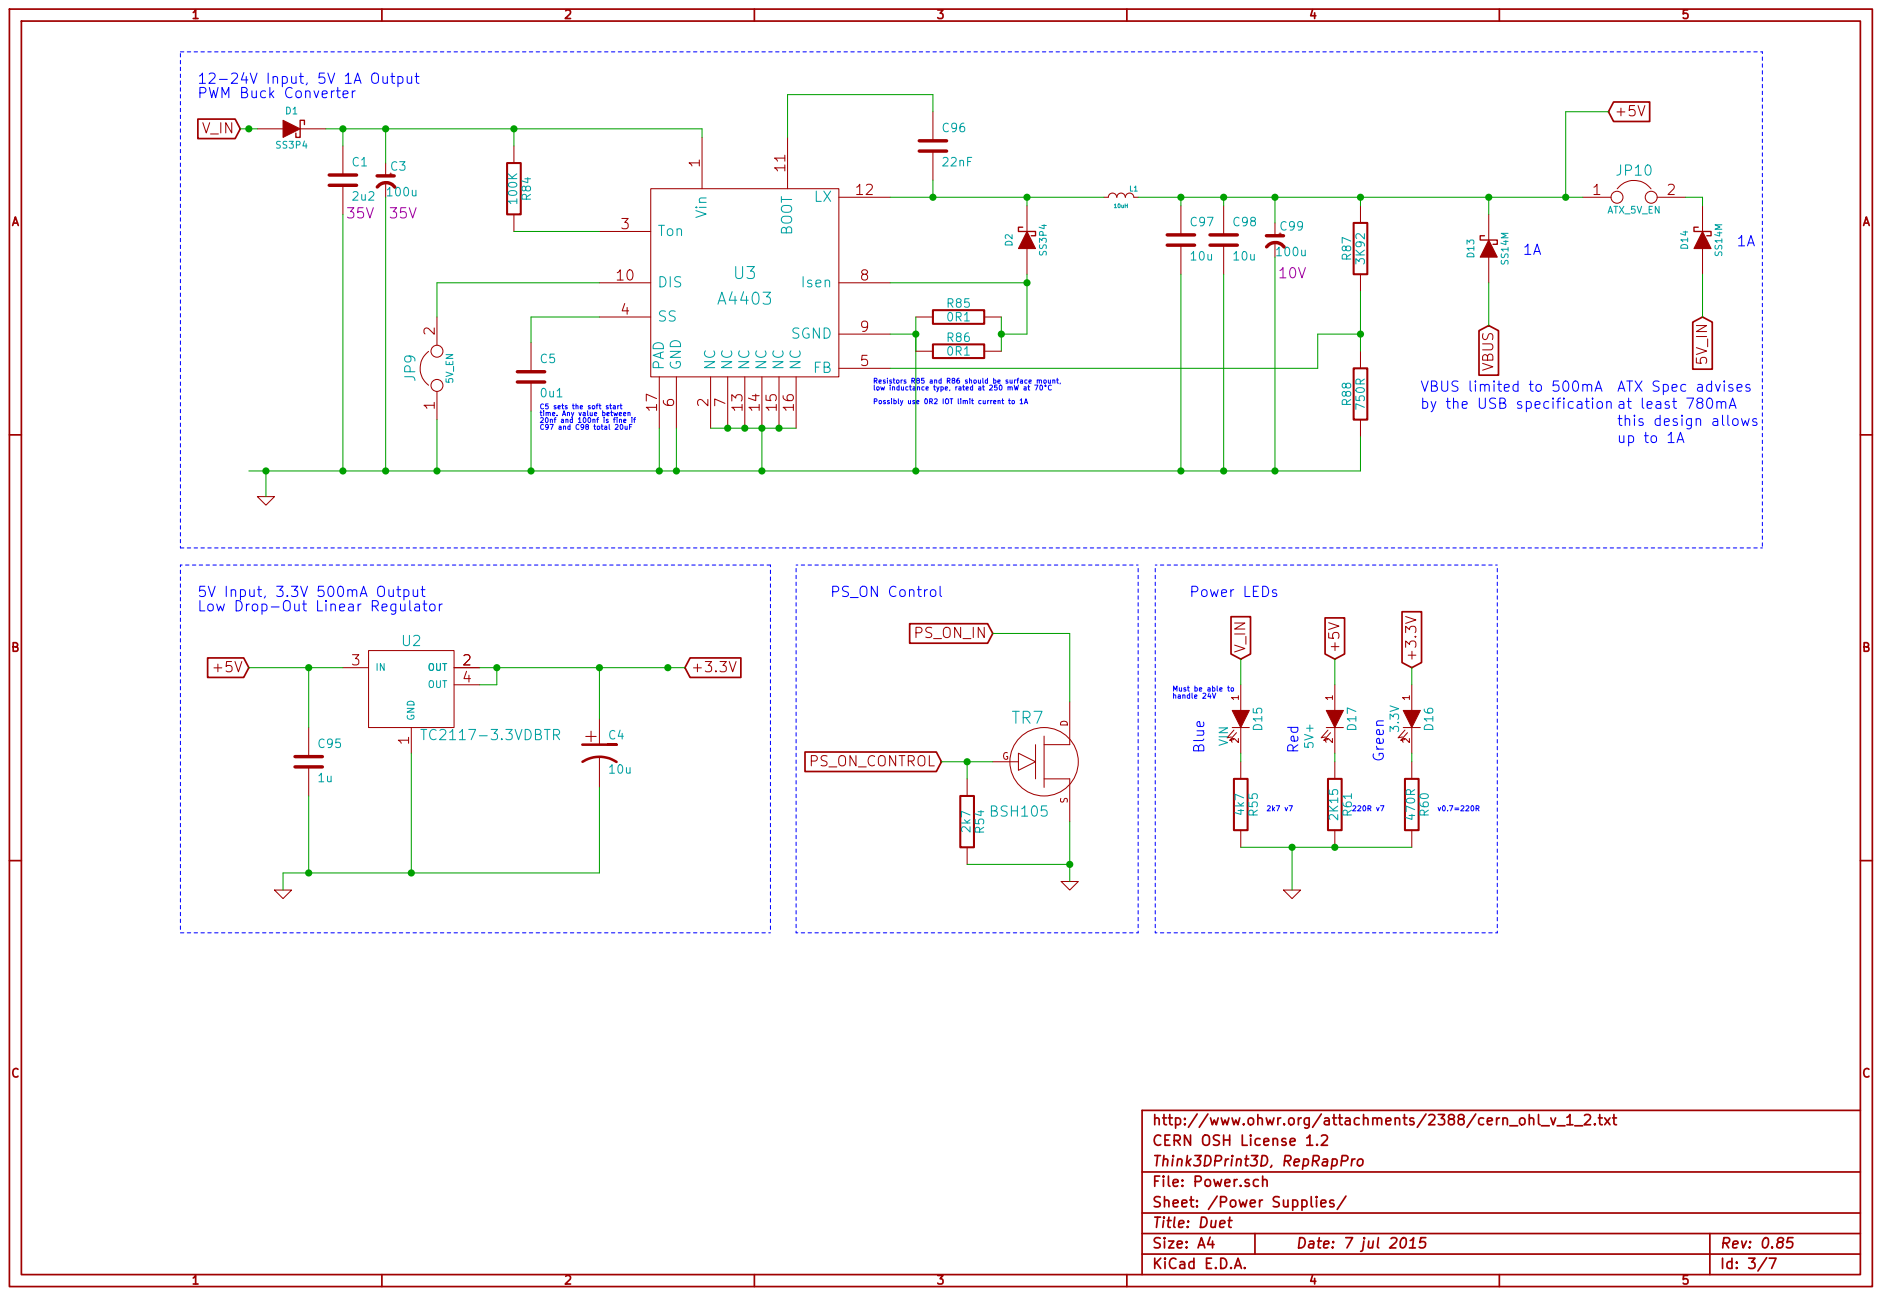
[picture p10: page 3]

U3 A4403 | LX | 12 NC 13 NC 14 NC 15 NC 16 PAD 17

2 Ton 3 SS 4 FB GND 5

Resistors R85 and R86 should be surface mount,
low inductance type, rated at 250 mW at 70°C

Possibly use 0R2 IOT limit current to 1A C5 sets the soft start

by the USB specification

this design allows at least 780mA

time. Any value between

5V Input, 3.3V 500mA Output
Low Drop-Out Linear Regulator

Must be able to

http://www.ohwr.org/attachments/2388/cern_ohl_v_1_2.txt C95

CERN OSH License 1.2
Think3DPrint3D, RepRapPro
Id: 3/7 Title: Duet File: Power.sch Sheet: /Power Supplies/

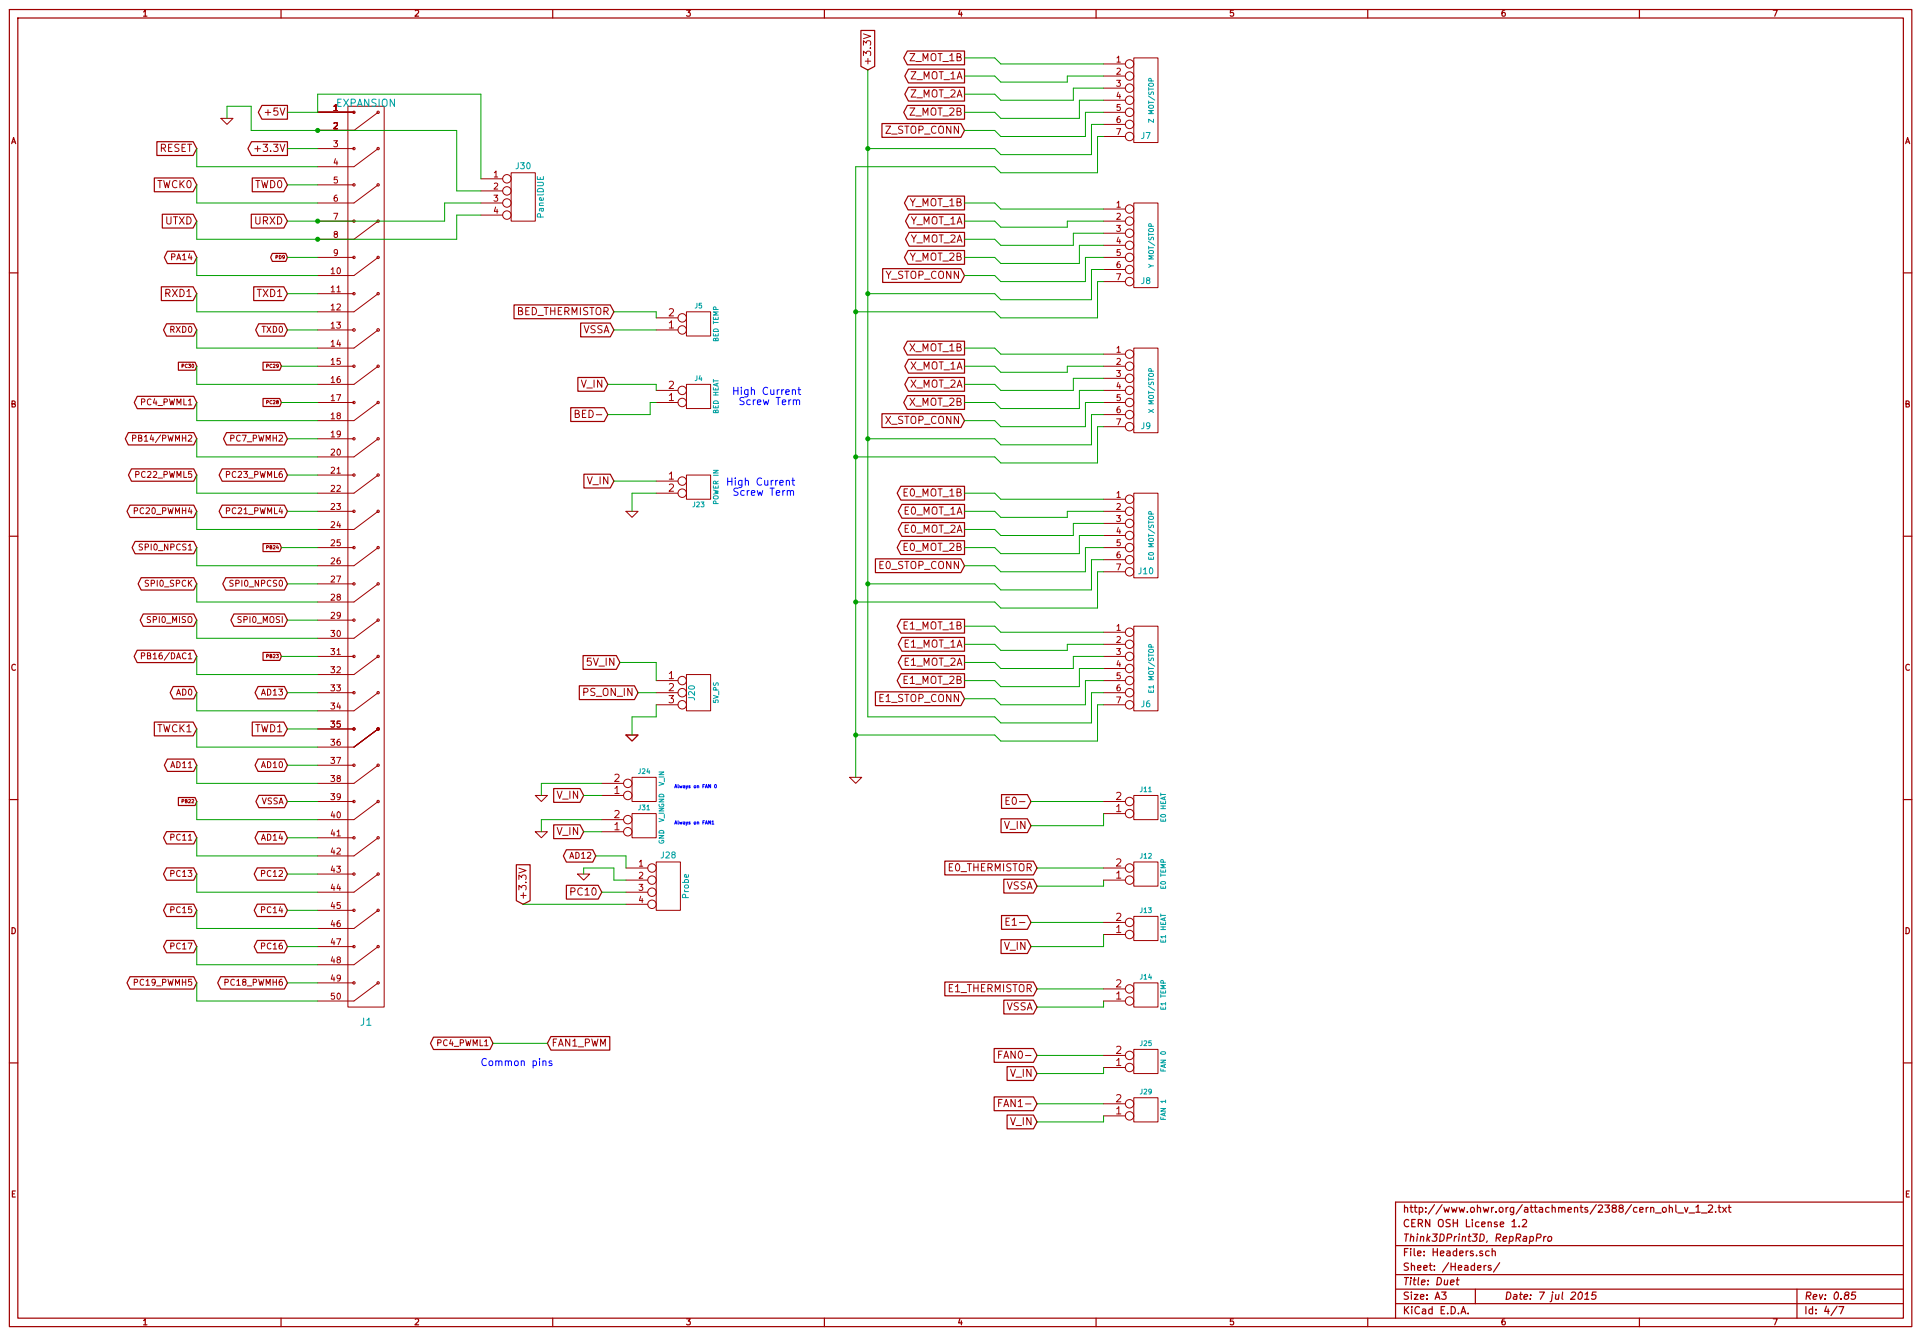
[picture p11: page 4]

CERN OSH License 1.2
Think3DPrint3D, RepRapPro
Id: 4/7 Title: Duet File: Headers.sch Sheet: /Headers/

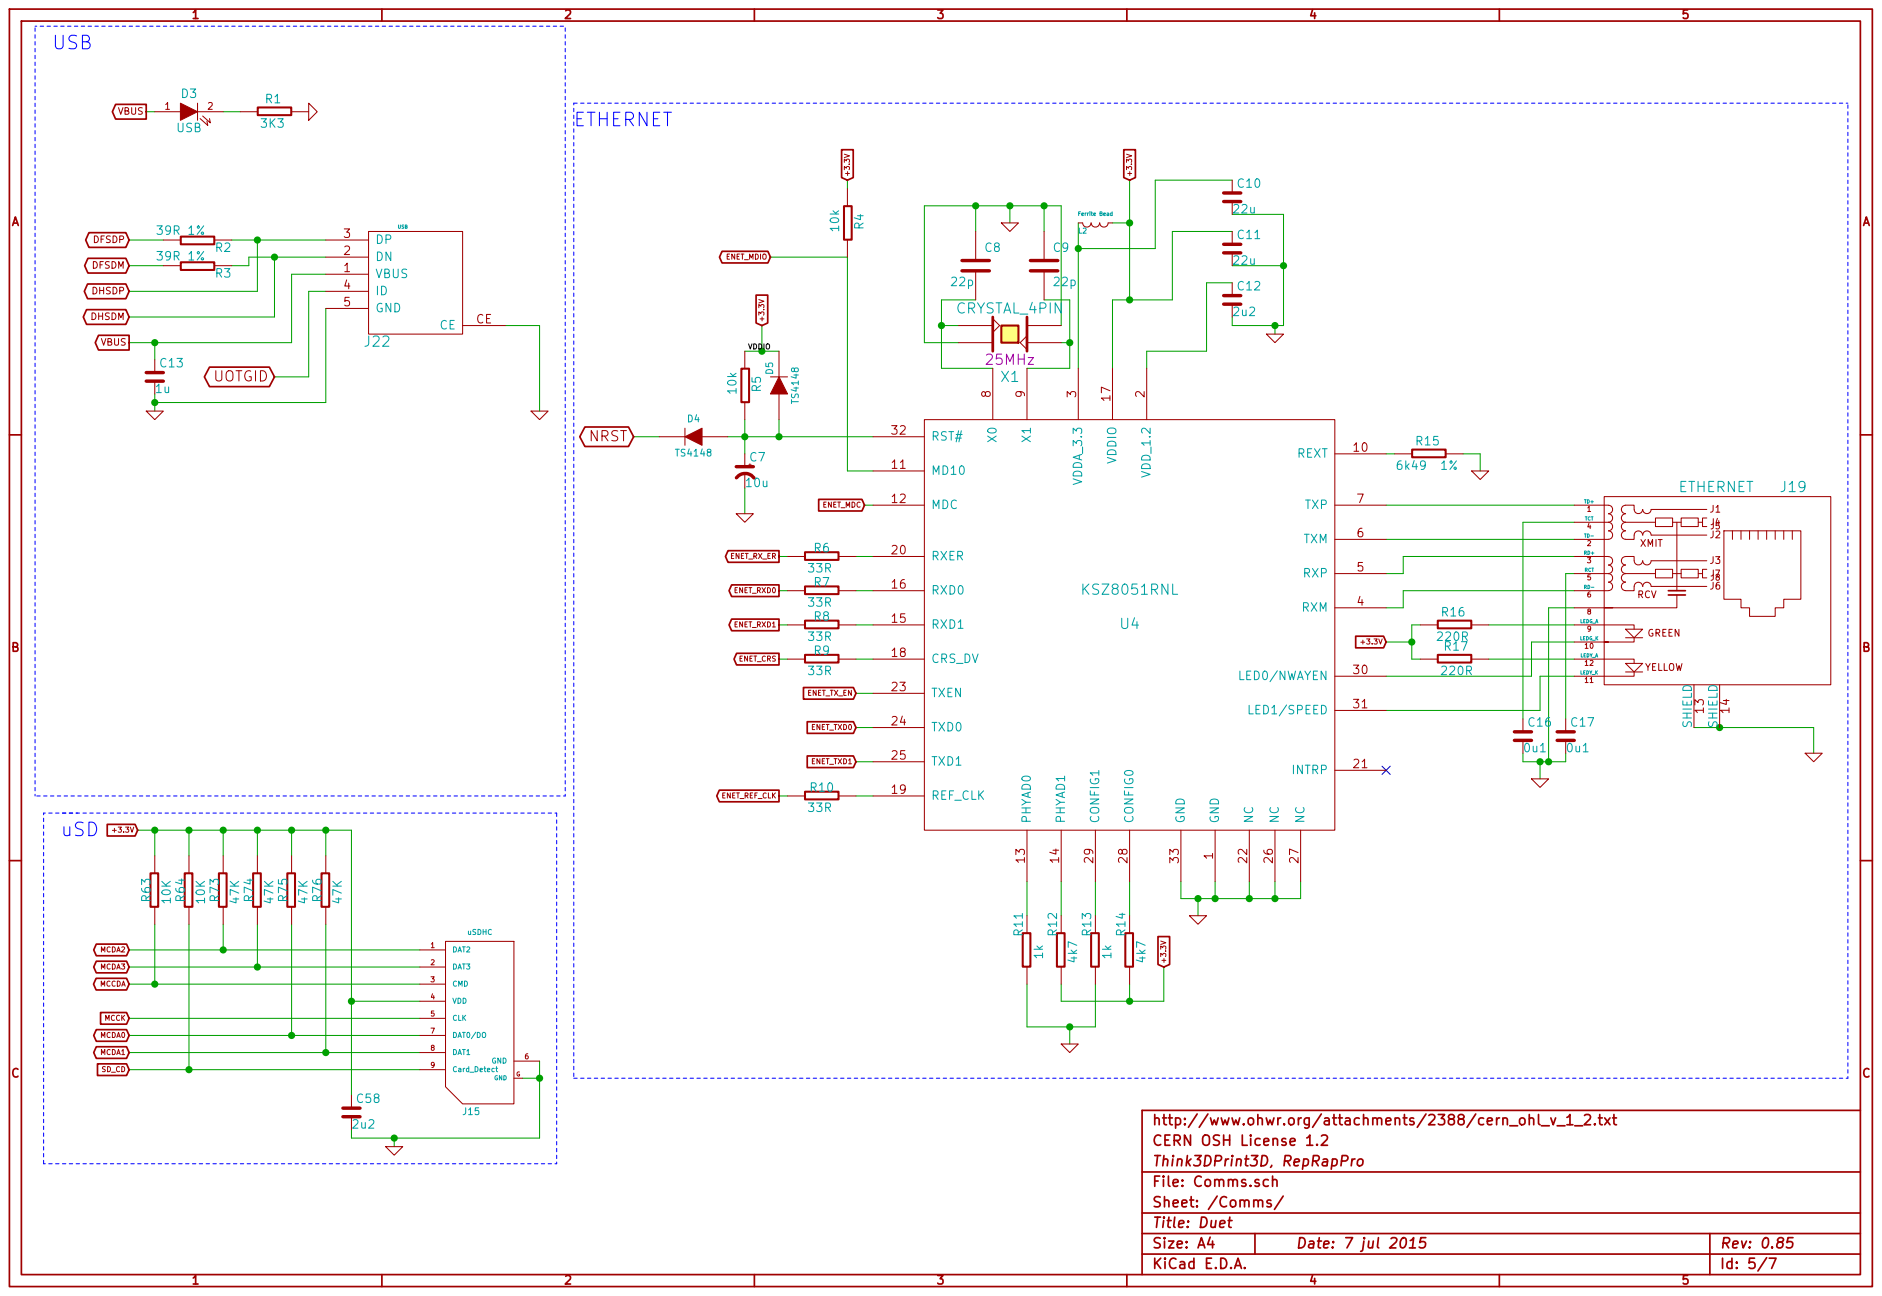
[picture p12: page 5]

3 RXM 4 RXP 5 TXM 6 TXP 7 X0

XMIT YELLOW | J1

GREEN

CERN OSH License 1.2
Think3DPrint3D, RepRapPro
Id: 5/7 Title: Duet File: Comms.sch
Sheet: /Comms/

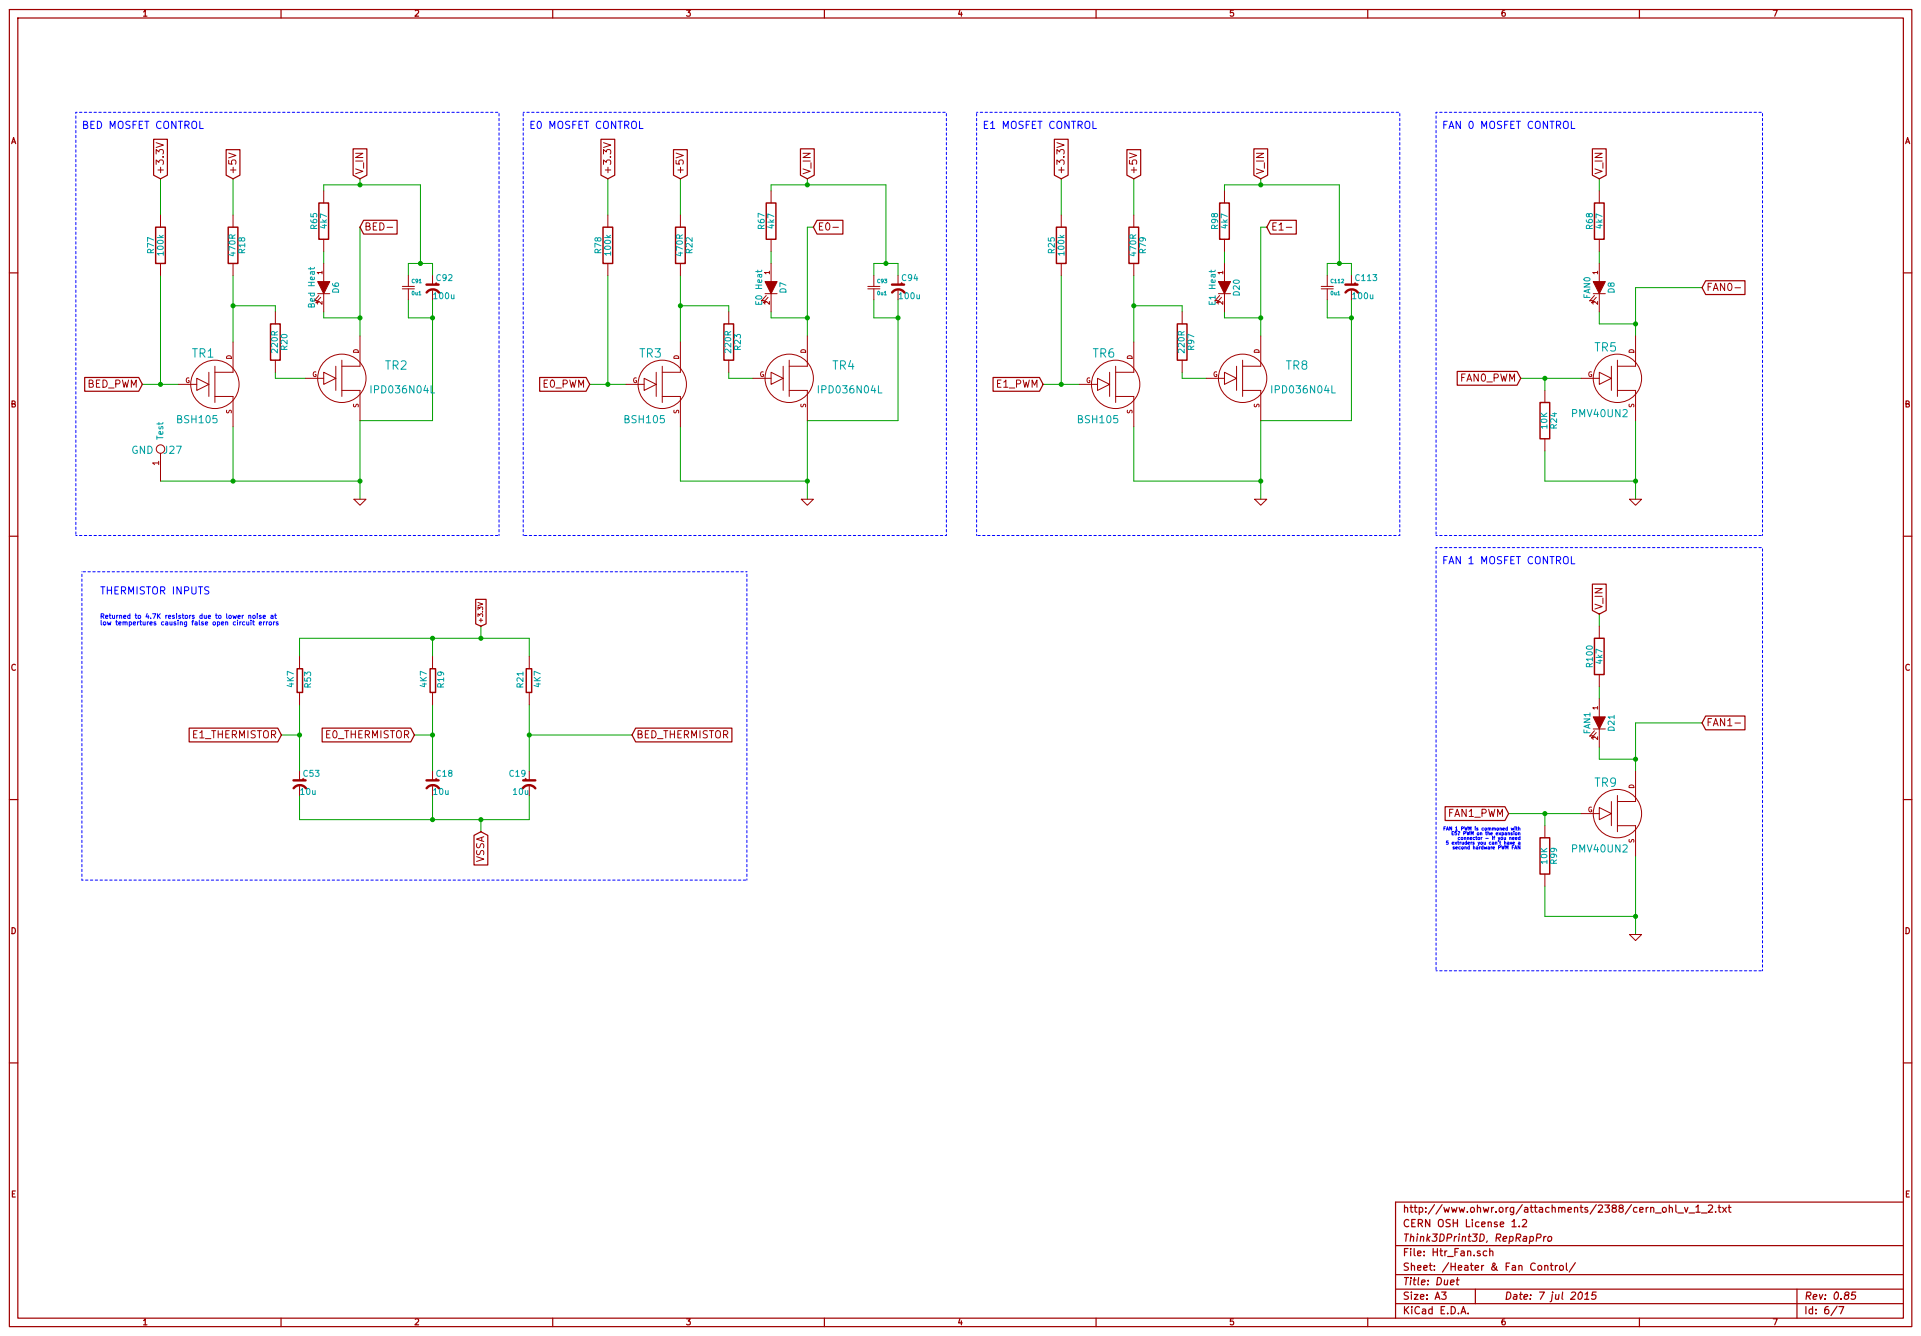
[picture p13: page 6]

10u +3.3V Returned to 4.7K resistors due to lower noise at
low tempertures causing false open circuit errors

FAN 1 PWM is commoned with E5? PWM on the expansion
connector - If you need
5 extruders you can't have a
second hardware PWM FAN

http://www.ohwr.org/attachments/2388/cern_ohl_v_1_2.txt
CERN OSH License 1.2
Think3DPrint3D, RepRapPro
Id: 6/7 Title: Duet File: Htr_Fan.sch
Sheet: /Heater & Fan Control/

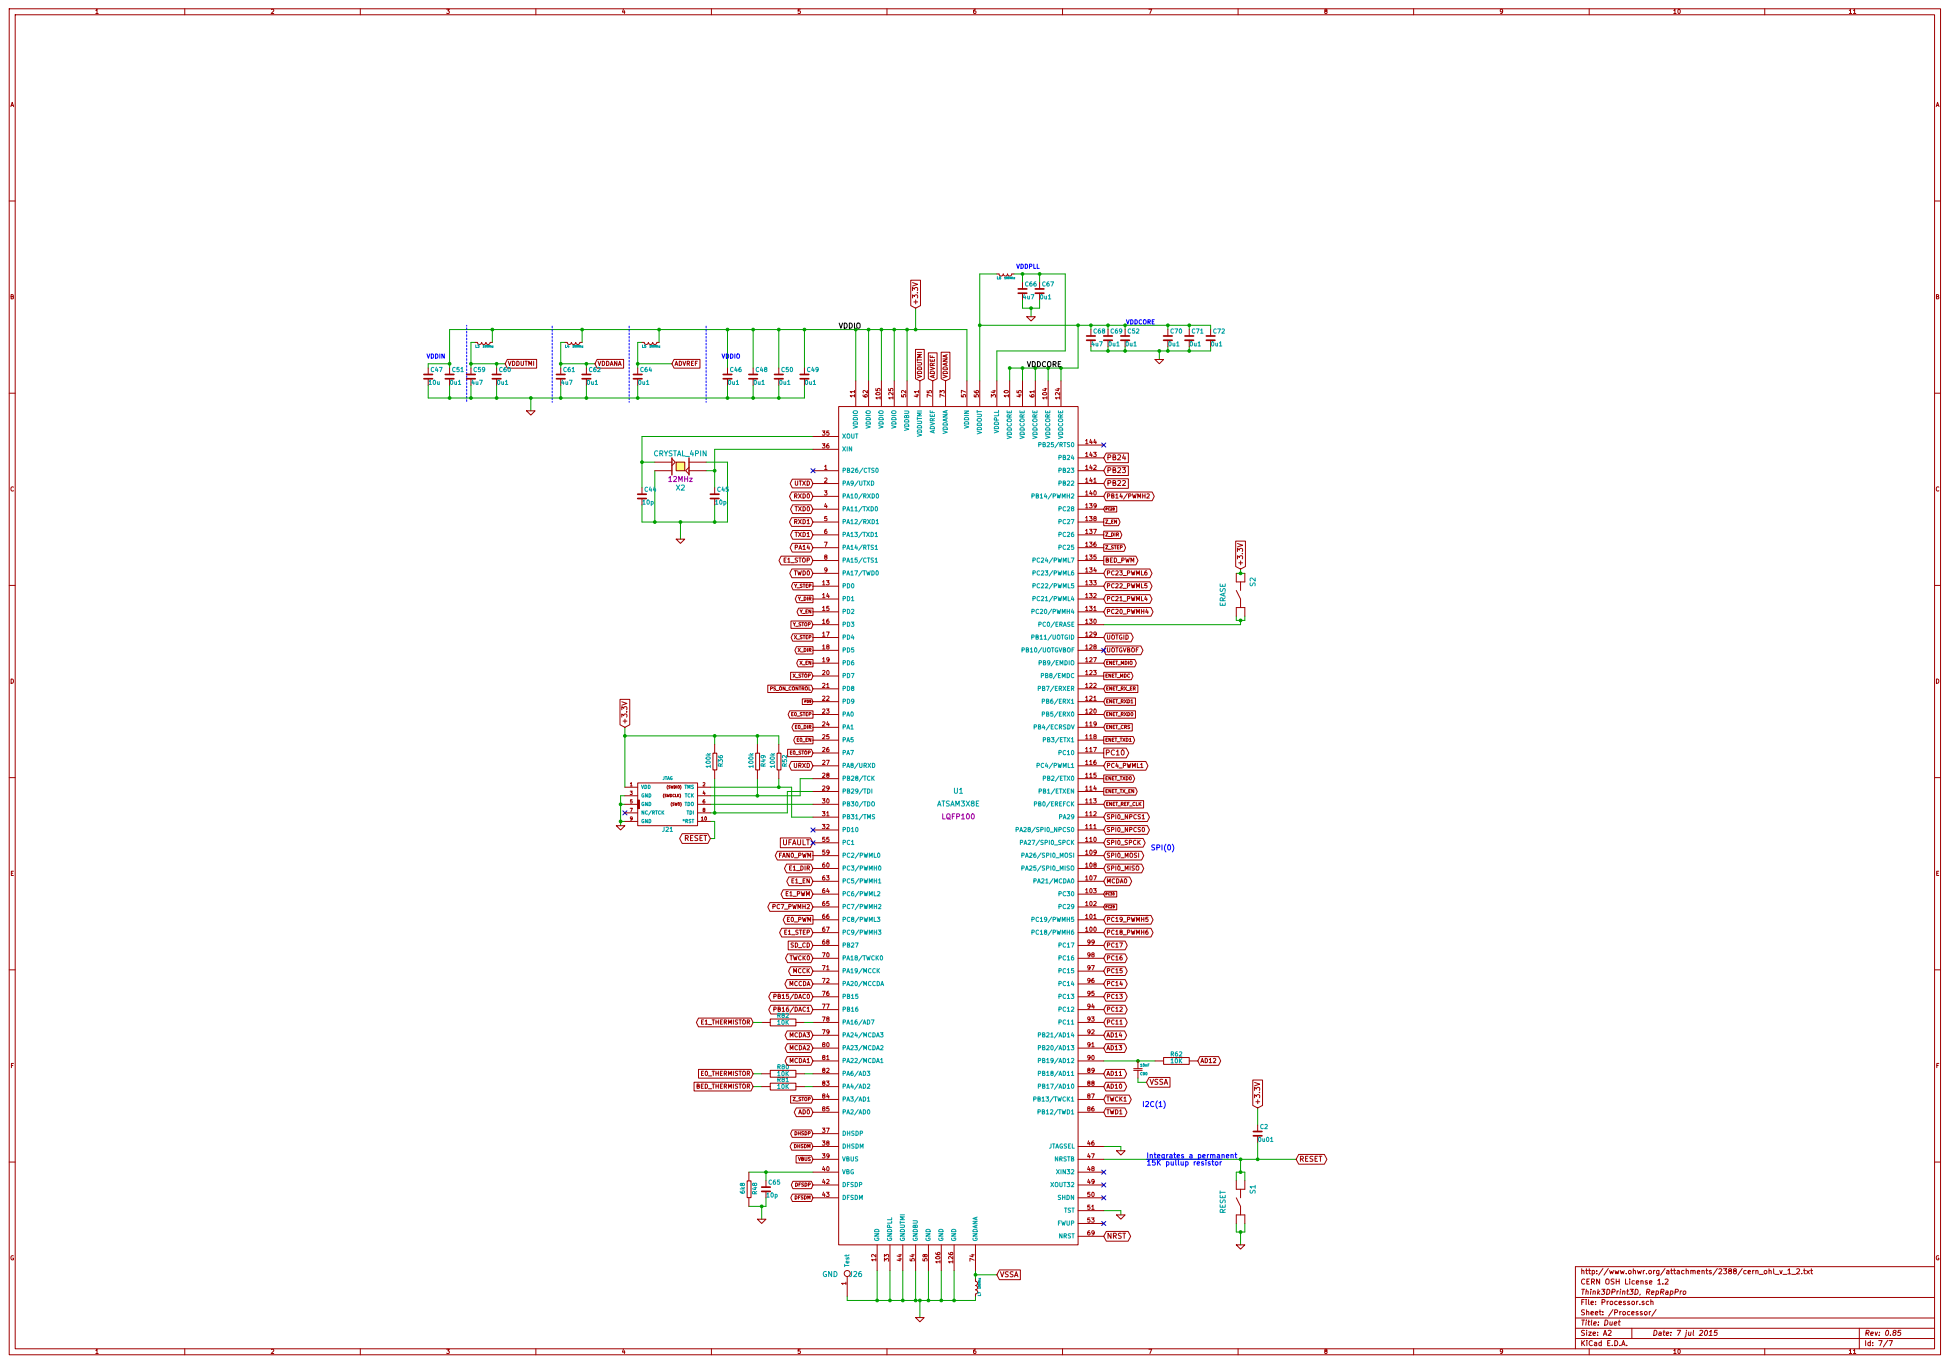
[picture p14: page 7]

http://www.ohwr.org/attachments/2388/cern_ohl_v_1_2.txt R81

CERN OSH License 1.2
Think3DPrint3D, RepRapPro
Id: 7/7 Title: Duet File: Processor.sch Sheet: /Processor/

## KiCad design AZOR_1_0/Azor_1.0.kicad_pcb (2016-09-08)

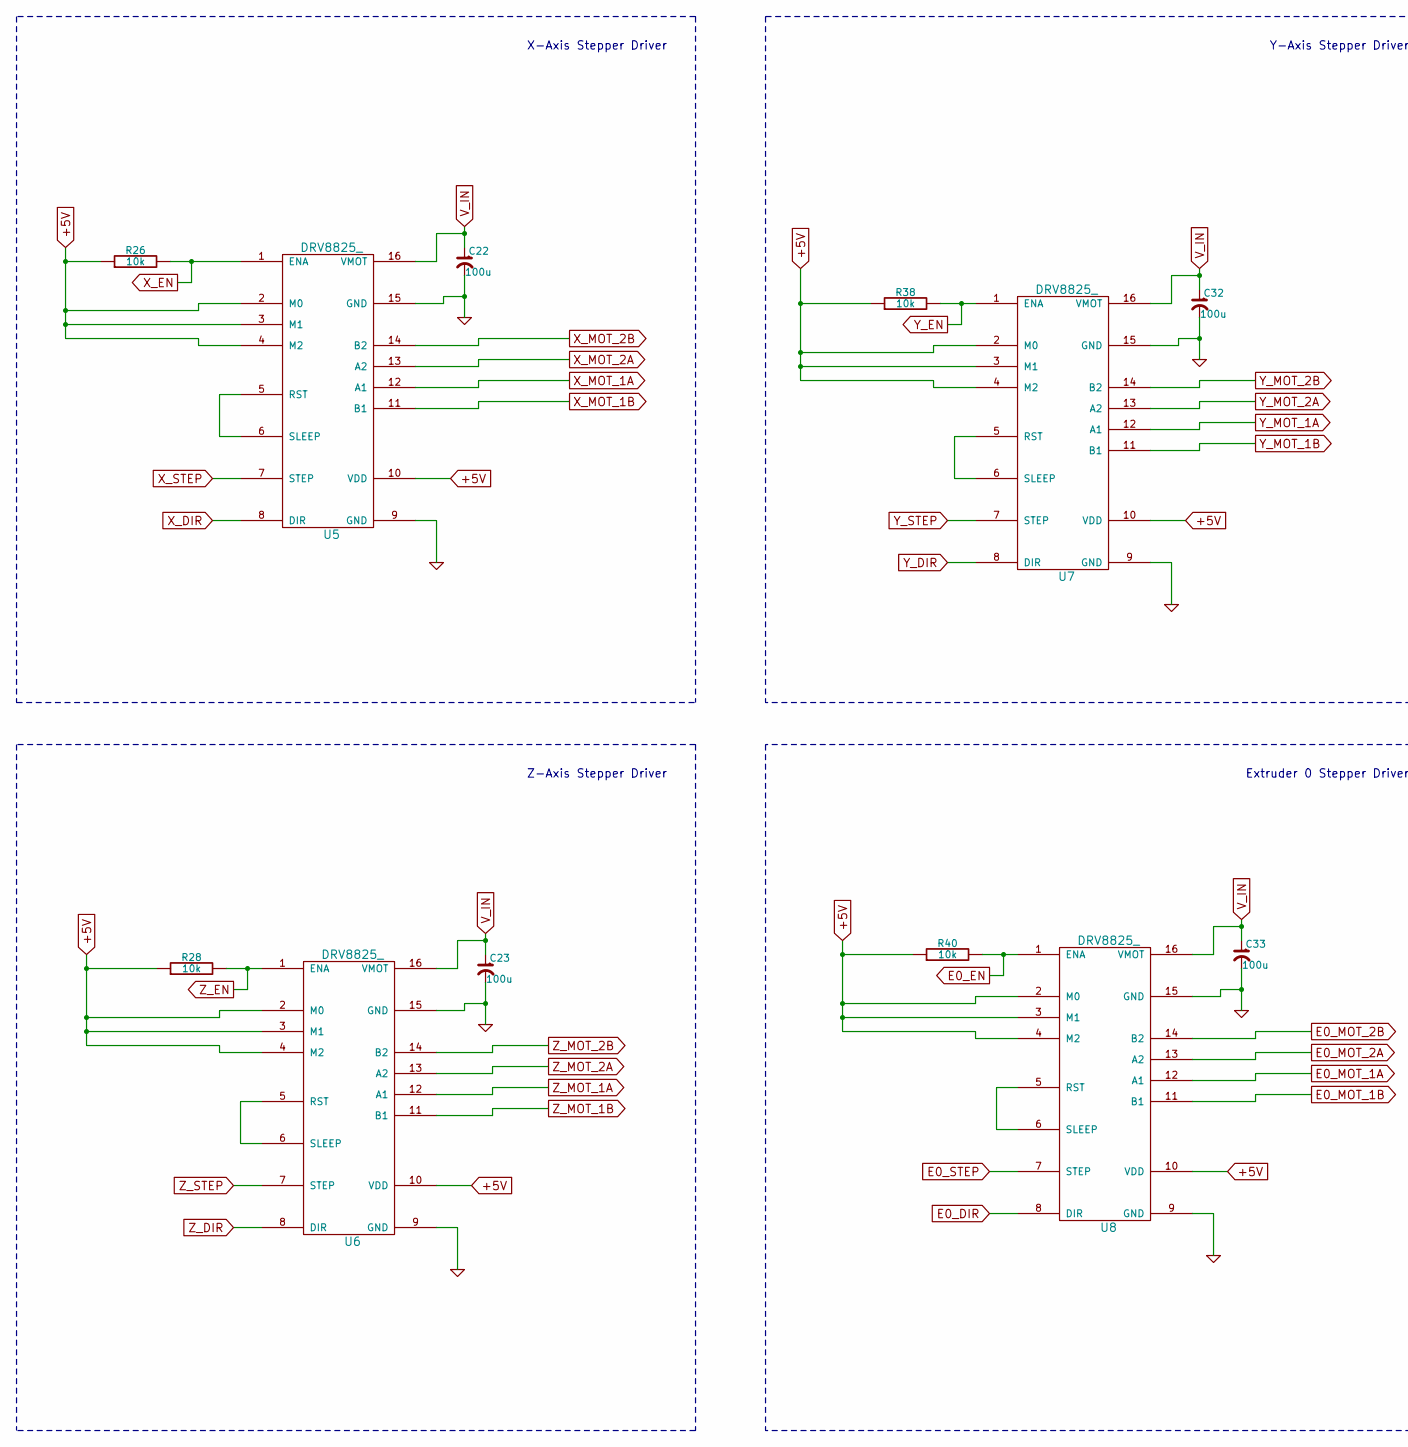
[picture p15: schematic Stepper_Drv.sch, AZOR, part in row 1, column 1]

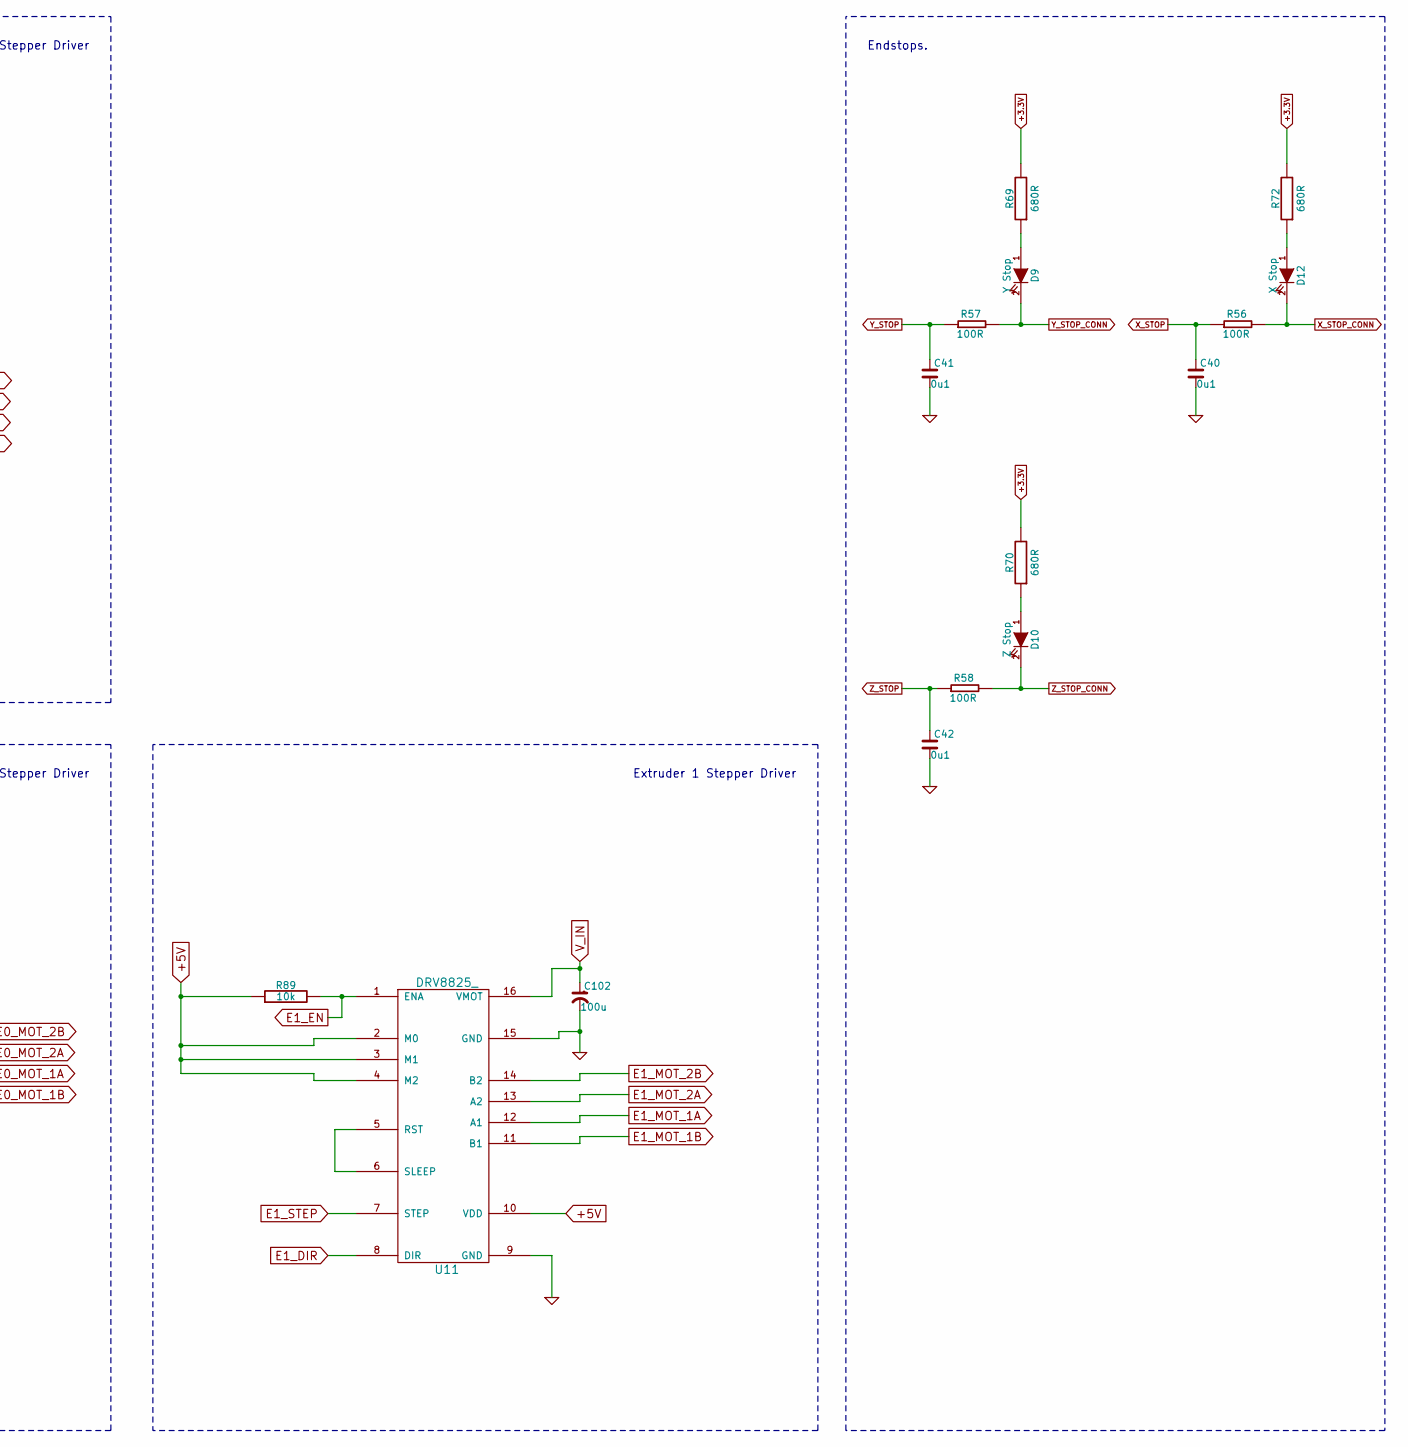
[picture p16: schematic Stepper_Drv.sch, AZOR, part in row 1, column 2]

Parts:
C22, C23, C32, C33, C102: 100u; c_elec_6.3x7.7
C40, C41, C42: 0u1; C_0603
D9: Y Stop; LED_0603
D10: Z Stop; LED_0603
D12: X Stop; LED_0603
R26, R28, R38, R40, R89: 10k; R_0603
R56, R57, R58: 100R; R_0603
R69, R70, R72: 680R; R_0603
U5, U6, U7, U8, U11: DRV8825_; DRV8825

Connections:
+3.3V: R69.2, R70.2, R72.2; also elsewhere on the board
+5V: R26.1, R28.1, R38.1, R40.1, R89.1, U5.2 (M0), U5.3 (M1), U5.4 (M2), U5.10 (VDD), U6.2 (M0), U6.3 (M1), U6.4 (M2), U6.10 (VDD), U7.2 (M0), U7.3 (M1), U7.4 (M2), U7.10 (VDD), U8.2 (M0), U8.3 (M1), U8.4 (M2), U8.10 (VDD), U11.2 (M0), U11.3 (M1), U11.4 (M2), U11.10 (VDD); also elsewhere on the board
E0_DIR: U8.8 (DIR); also elsewhere on the board
E0_EN: R40.2, U8.1 (ENA); also elsewhere on the board
E0_MOT_1A: U8.12 (A1); also elsewhere on the board
E0_MOT_1B: U8.11 (B1); also elsewhere on the board
E0_MOT_2A: U8.13 (A2); also elsewhere on the board
E0_MOT_2B: U8.14 (B2); also elsewhere on the board
E0_STEP: U8.7 (STEP); also elsewhere on the board
E1_DIR: U11.8 (DIR); also elsewhere on the board
E1_EN: R89.2, U11.1 (ENA); also elsewhere on the board
E1_MOT_1A: U11.12 (A1); also elsewhere on the board
E1_MOT_1B: U11.11 (B1); also elsewhere on the board
E1_MOT_2A: U11.13 (A2); also elsewhere on the board
E1_MOT_2B: U11.14 (B2); also elsewhere on the board
E1_STEP: U11.7 (STEP); also elsewhere on the board
GND: C22.2, C23.2, C32.2, C33.2, C40.2, C41.2, C42.2, C102.2, U5.9 (GND), U5.15 (GND), U6.9 (GND), U6.15 (GND), U7.9 (GND), U7.15 (GND), U8.9 (GND), U8.15 (GND), U11.9 (GND), U11.15 (GND); also elsewhere on the board
unnamed: D9.1 (A), R69.1
unnamed: D10.1 (A), R70.1
unnamed: D12.1 (A), R72.1
unnamed: U5.5 (RST), U5.6 (SLEEP)
unnamed: U6.5 (RST), U6.6 (SLEEP)
unnamed: U7.5 (RST), U7.6 (SLEEP)
unnamed: U8.5 (RST), U8.6 (SLEEP)
unnamed: U11.5 (RST), U11.6 (SLEEP)
V_IN: C22.1, C23.1, C32.1, C33.1, C102.1, U5.16 (VMOT), U6.16 (VMOT), U7.16 (VMOT), U8.16 (VMOT), U11.16 (VMOT); also elsewhere on the board
X_DIR: U5.8 (DIR); also elsewhere on the board
X_EN: R26.2, U5.1 (ENA); also elsewhere on the board
X_MOT_1A: U5.12 (A1); also elsewhere on the board
X_MOT_1B: U5.11 (B1); also elsewhere on the board
X_MOT_2A: U5.13 (A2); also elsewhere on the board
X_MOT_2B: U5.14 (B2); also elsewhere on the board
X_STEP: U5.7 (STEP); also elsewhere on the board
X_STOP: C40.1, R56.1; also elsewhere on the board
X_STOP_CONN: D12.2 (K), R56.2; also elsewhere on the board
Y_DIR: U7.8 (DIR); also elsewhere on the board
Y_EN: R38.2, U7.1 (ENA); also elsewhere on the board
Y_MOT_1A: U7.12 (A1); also elsewhere on the board
Y_MOT_1B: U7.11 (B1); also elsewhere on the board
Y_MOT_2A: U7.13 (A2); also elsewhere on the board
Y_MOT_2B: U7.14 (B2); also elsewhere on the board
Y_STEP: U7.7 (STEP); also elsewhere on the board
Y_STOP: C41.1, R57.1; also elsewhere on the board
Y_STOP_CONN: D9.2 (K), R57.2; also elsewhere on the board
Z_DIR: U6.8 (DIR); also elsewhere on the board
Z_EN: R28.2, U6.1 (ENA); also elsewhere on the board
Z_MOT_1A: U6.12 (A1); also elsewhere on the board
Z_MOT_1B: U6.11 (B1); also elsewhere on the board
Z_MOT_2A: U6.13 (A2); also elsewhere on the board
Z_MOT_2B: U6.14 (B2); also elsewhere on the board
Z_STEP: U6.7 (STEP); also elsewhere on the board
Z_STOP: C42.1, R58.1; also elsewhere on the board
Z_STOP_CONN: D10.2 (K), R58.2; also elsewhere on the board

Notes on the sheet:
Endstops.
Z-Axis Stepper Driver
Extruder 0 Stepper Driver
Y-Axis Stepper Driver
X-Axis Stepper Driver
Extruder 1 Stepper Driver

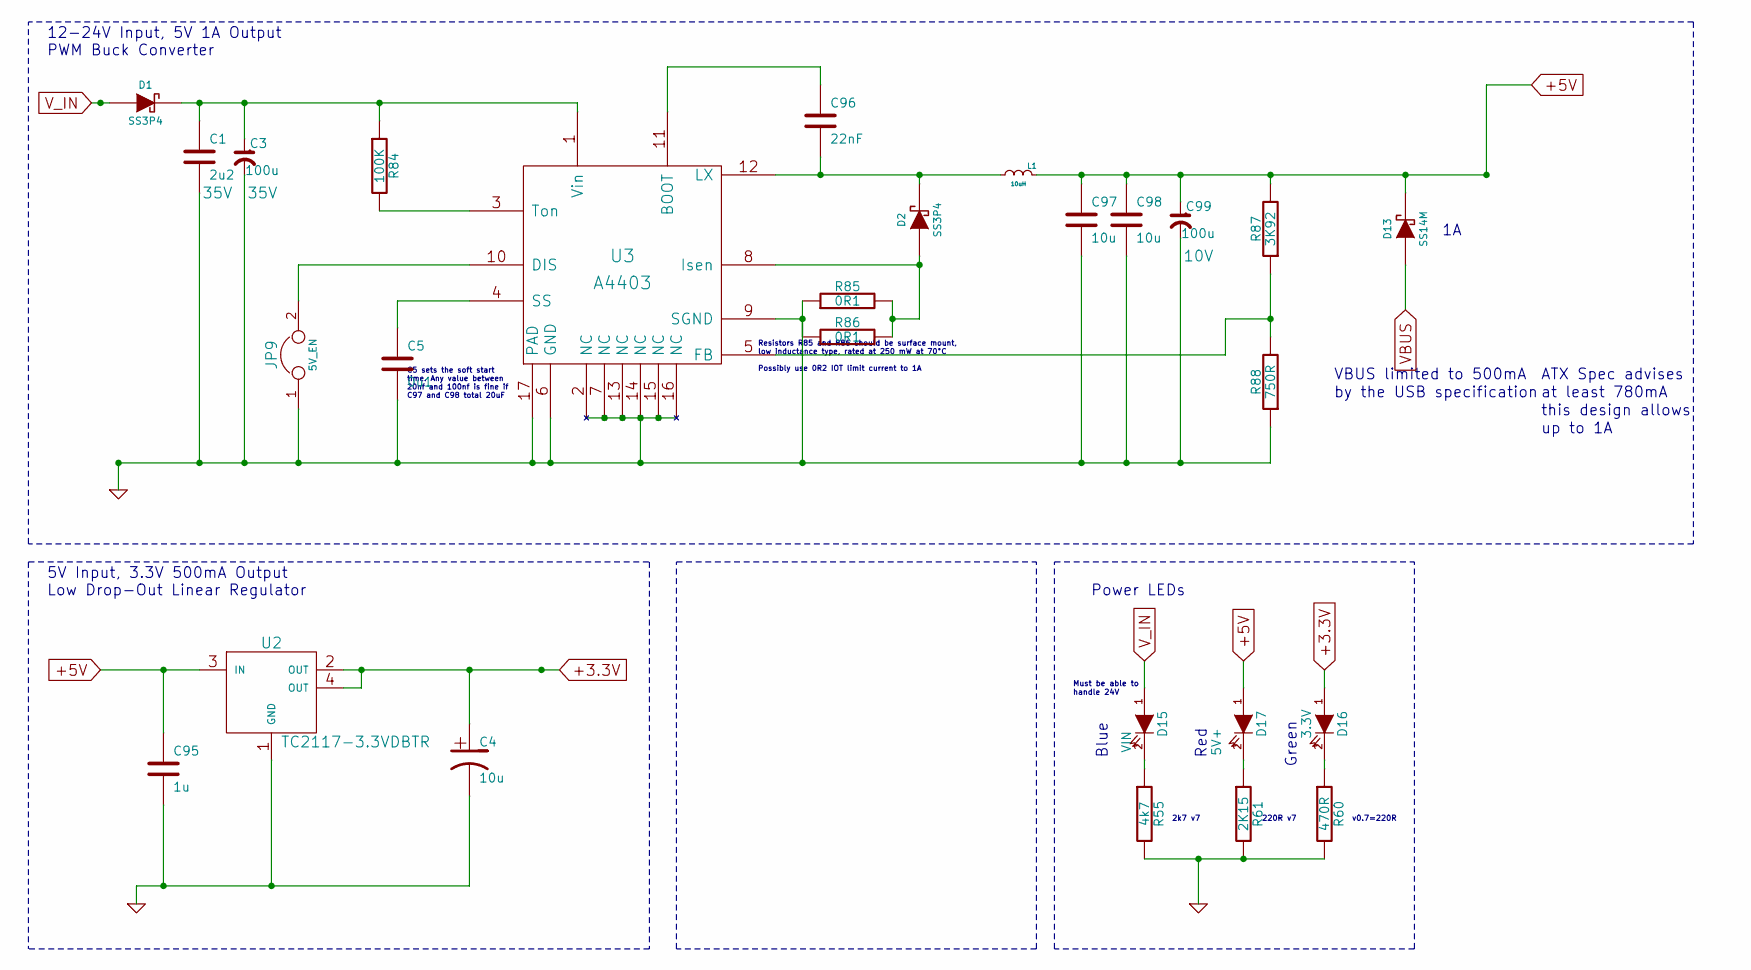
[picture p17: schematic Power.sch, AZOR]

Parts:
C1: 2u2; C_0603; Voltage 35V
C3: 100u; c_elec_6.3x7.7; Voltage 35V
C4, C97, C98: 10u; C_0805
C5: 0u1; C_0603
C95: 1u; C_0603
C96: 22nF; C_0603
C99: 100u; c_elec_6.3x7.7; Voltage 10V
D1, D2: SS3P4; DO-220AA
D13: SS14M; uSMA
D15: VIN; LED_0603
D16: 3.3V; LED_0603
D17: 5V+; LED_0603
JP9: 5V_EN; Pin_Header_Straight_1x02
L1: 10uH; L_6x6
R55: 4k7; R_0603
R60: 470R; R_0603
R61: 2K15; R_0603
R84: 100K; R_0603
R85, R86: 0R1; R_1206
R87: 3K92; R_0603
R88: 750R; R_0603
U2: TC2117-3.3VDBTR; SOT-223
U3: A4403; QFN16-4x4

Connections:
+3.3V: C4.1, D16.1 (A), U2.2 (OUT), U2.4 (OUT); also elsewhere on the board
+5V: C95.1, C97.1, C98.1, C99.1, D13.2 (K), D17.1 (A), L1.1 (A), R87.2, U2.3 (IN); also elsewhere on the board
GND: C1.2, C3.2, C4.2, C5.2, C95.2, C97.2, C98.2, C99.2, JP9.1, R55.2, R60.2, R61.2, R85.1, R86.1, R88.1, U2.1 (GND), U3.2 (NC), U3.6 (GND), U3.7 (NC), U3.9 (SGND), U3.13 (NC), U3.14 (NC), U3.15 (NC), U3.16 (NC), U3.17 (PAD); also elsewhere on the board
unnamed: C1.1, C3.1, D1.2 (K), R84.1, U3.1 (Vin)
unnamed: C5.1, U3.4 (SS)
unnamed: C96.1, U3.11 (BOOT)
unnamed: C96.2, D2.2 (K), L1.2 (B), U3.12 (LX)
unnamed: D2.1 (A), R85.2, R86.2, U3.8 (Isen)
unnamed: D15.2 (K), R55.1
unnamed: D16.2 (K), R60.1
unnamed: D17.2 (K), R61.1
unnamed: JP9.2, U3.10 (DIS)
unnamed: R84.2, U3.3 (Ton)
unnamed: R87.1, R88.2, U3.5 (FB)
VBUS: D13.1 (A); also elsewhere on the board
V_IN: D1.1 (A), D15.1 (A); also elsewhere on the board

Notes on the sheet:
up to 1A
this design allows
at least 780mA
ATX Spec advises
by the USB specification
VBUS limited to 500mA
5V Input, 3.3V 500mA Output Low Drop-Out Linear Regulator
12-24V Input, 5V 1A Output PWM Buck Converter
2k7 v7
220R v7
v0.7=220R
Resistors R85 and R86 should be surface mount, low inductance type, rated at 250 mW at 70°C Possibly use 0R2 IOT limit current to 1A
C5 sets the soft start time. Any value between 20nf and 100nf is fine if C97 and C98 total 20uF
Power LEDs
Must be able to handle 24V
Blue
Red
Green

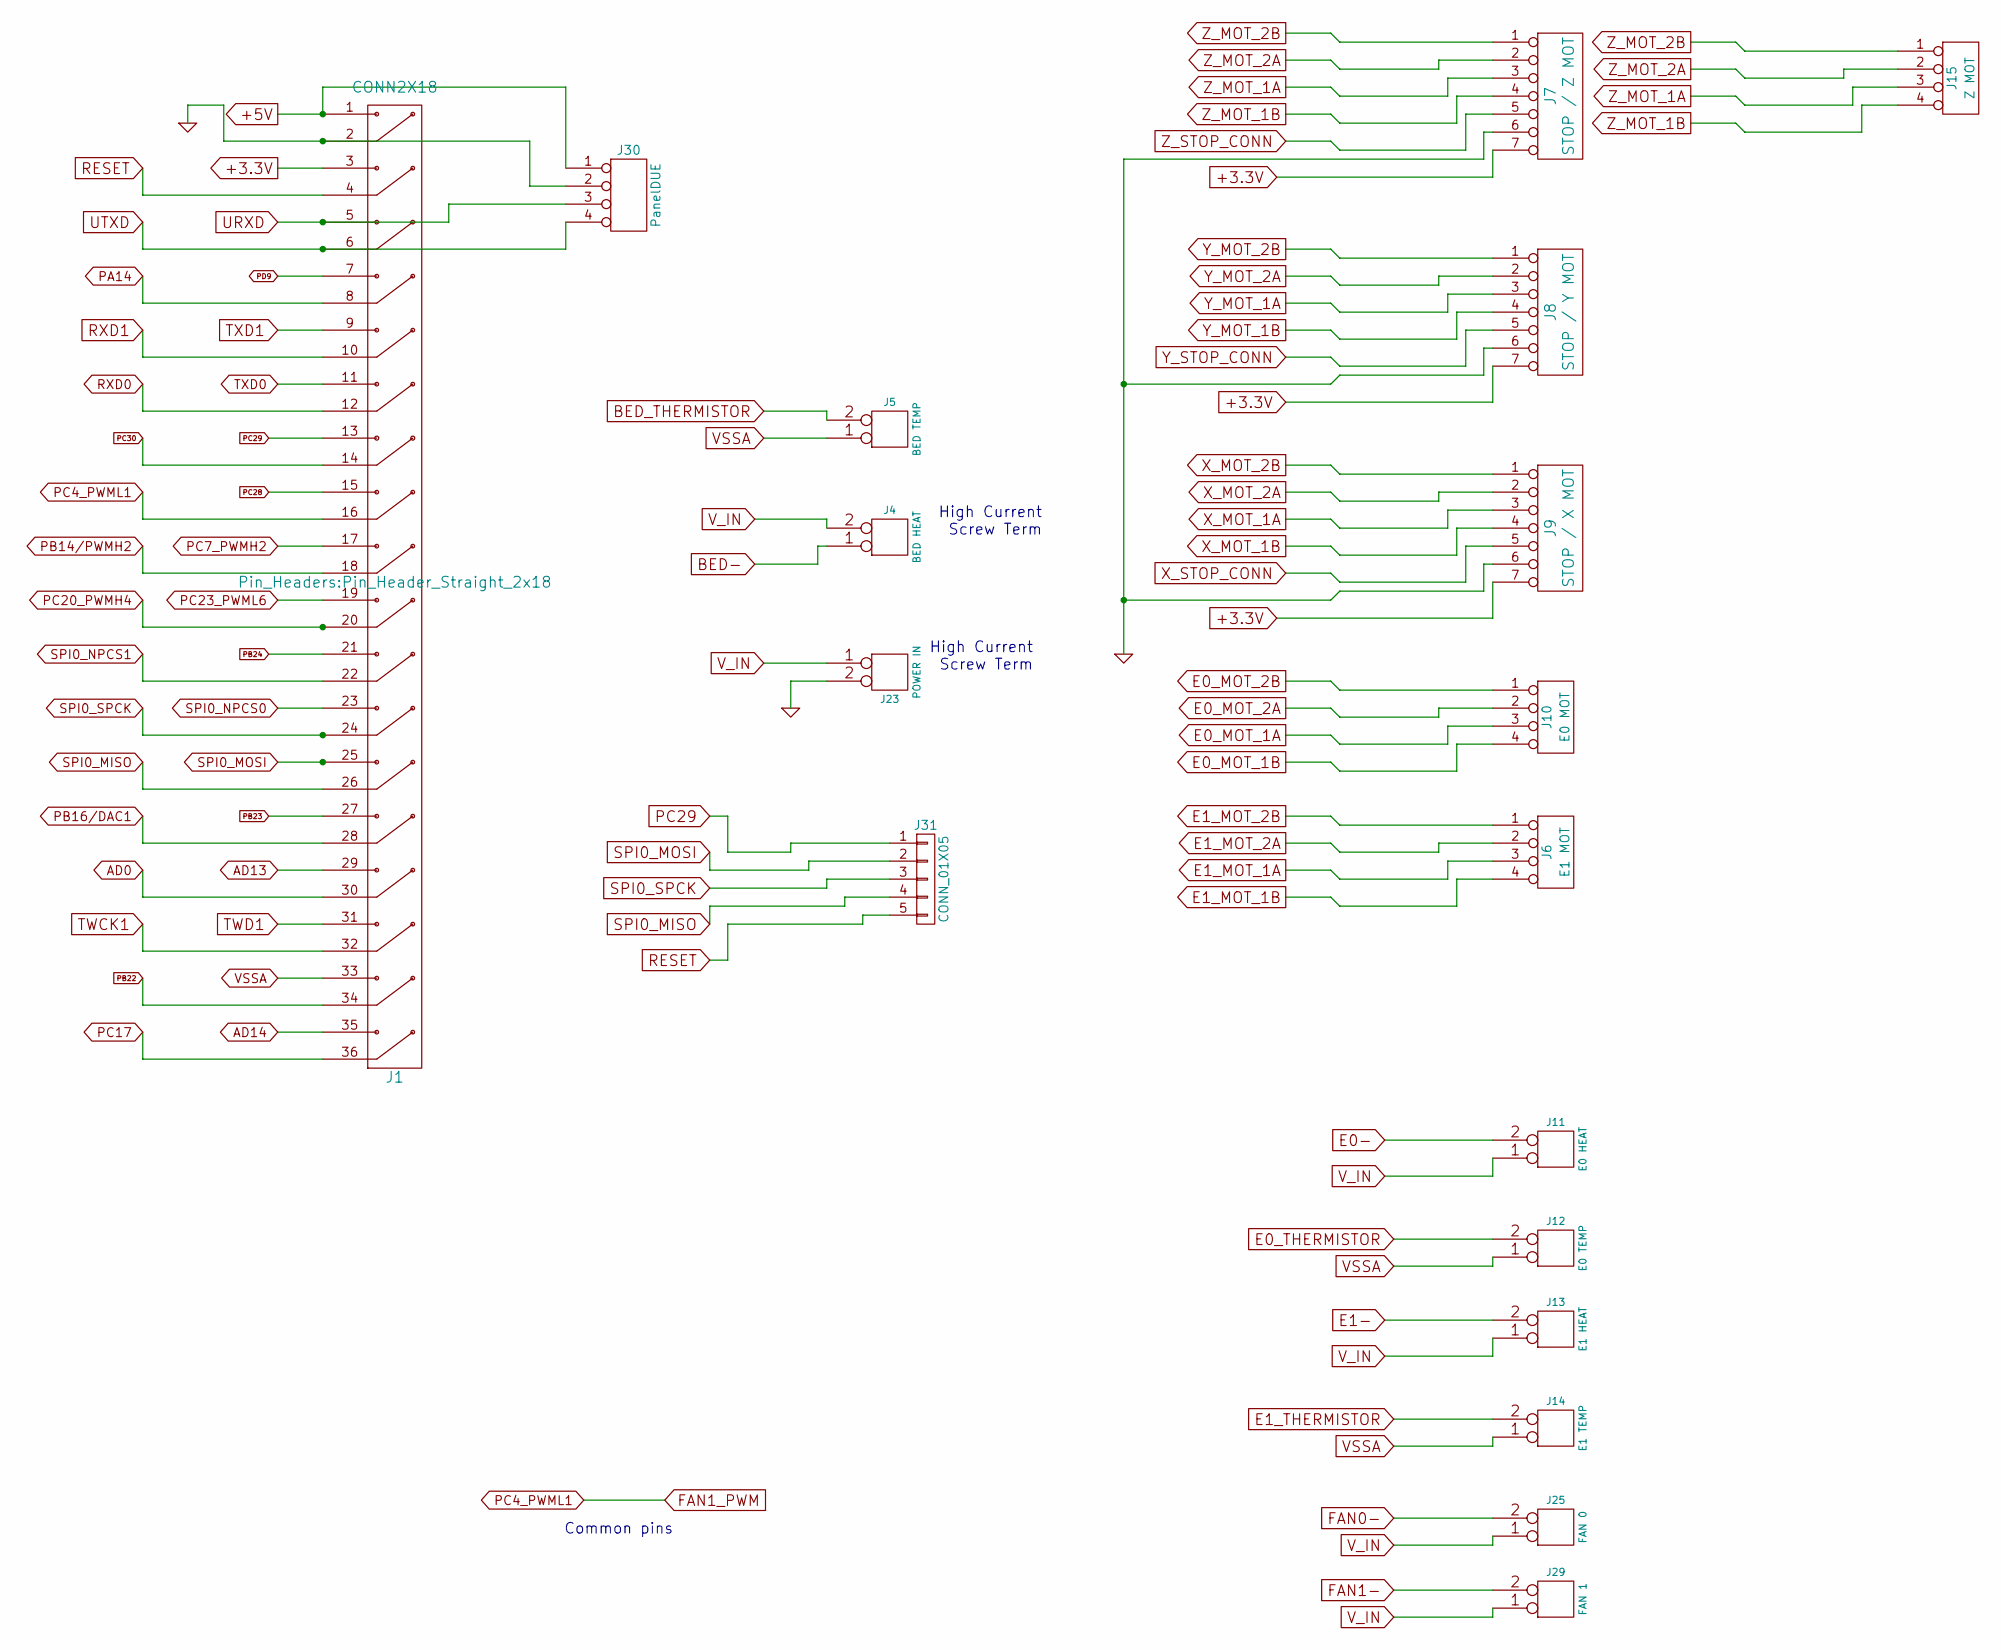
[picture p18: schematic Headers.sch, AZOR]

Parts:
J1: CONN2X18; Pin_Header_Straight_2x18
J4: BED HEAT; TERM_2-WAY_6.35mm
J5: BED TEMP; Pin_Header_Straight_1x02
J6: E1 MOT; Pin_Header_Straight_1x04
J7: STOP / Z MOT; Pin_Header_Straight_1x07
J8: STOP / Y MOT; Pin_Header_Straight_1x07
J9: STOP / X MOT; Pin_Header_Straight_1x07
J10: E0 MOT; Pin_Header_Straight_1x04
J11: E0 HEAT; PHOENIX_CONNECTOR_2
J12: E0 TEMP; Pin_Header_Straight_1x02
J13: E1 HEAT; PHOENIX_CONNECTOR_2
J14: E1 TEMP; Pin_Header_Straight_1x02
J15: Z MOT; Pin_Header_Straight_1x04
J23: POWER IN; PHOENIX_CONNECTOR_2
J25: FAN 0; Pin_Header_Straight_1x02
J29: FAN 1; Pin_Header_Straight_1x02
J30: PanelDUE; Molex_KK-6410-04_04x2.54mm_Straight
J31: CONN_01X05; Molex_KK-6410-05_05x2.54mm_Straight

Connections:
+3.3V: J1.3, J7.7, J8.7, J9.7; also elsewhere on the board
+5V: J1.1, J30.1; also elsewhere on the board
AD0: J1.30; also elsewhere on the board
AD13: J1.29; also elsewhere on the board
AD14: J1.35; also elsewhere on the board
BED-: J4.1; also elsewhere on the board
BED_THERMISTOR: J5.2 (PM); also elsewhere on the board
E0-: J11.2 (PM); also elsewhere on the board
E0_MOT_1A: J10.3; also elsewhere on the board
E0_MOT_1B: J10.4; also elsewhere on the board
E0_MOT_2A: J10.2; also elsewhere on the board
E0_MOT_2B: J10.1; also elsewhere on the board
E0_THERMISTOR: J12.2 (PM); also elsewhere on the board
E1-: J13.2 (PM); also elsewhere on the board
E1_MOT_1A: J6.3; also elsewhere on the board
E1_MOT_1B: J6.4; also elsewhere on the board
E1_MOT_2A: J6.2; also elsewhere on the board
E1_MOT_2B: J6.1; also elsewhere on the board
E1_THERMISTOR: J14.2 (PM); also elsewhere on the board
FAN0-: J25.2 (PM); also elsewhere on the board
FAN1-: J29.2 (PM); also elsewhere on the board
FAN1_PWM: J1.16; also elsewhere on the board
GND: J1.2, J7.6, J8.6, J9.6, J23.2 (PM), J30.2; also elsewhere on the board
PA14: J1.8; also elsewhere on the board
PB14/PWMH2: J1.18; also elsewhere on the board
PB16/DAC1: J1.28; also elsewhere on the board
PB22: J1.34; also elsewhere on the board
PB23: J1.27; also elsewhere on the board
PB24: J1.21; also elsewhere on the board
PC7_PWMH2: J1.17; also elsewhere on the board
PC17: J1.36; also elsewhere on the board
PC20_PWMH4: J1.20; also elsewhere on the board
PC23_PWML6: J1.19; also elsewhere on the board
PC28: J1.15; also elsewhere on the board
PC29: J1.13, J31.1; also elsewhere on the board
PC30: J1.14; also elsewhere on the board
PD9: J1.7; also elsewhere on the board
RESET: J1.4, J31.5; also elsewhere on the board
RXD0: J1.12; also elsewhere on the board
RXD1: J1.10; also elsewhere on the board
SPI0_MISO: J1.26, J31.4; also elsewhere on the board
SPI0_MOSI: J1.25, J31.2; also elsewhere on the board
SPI0_NPCS0: J1.23; also elsewhere on the board
SPI0_NPCS1: J1.22; also elsewhere on the board
SPI0_SPCK: J1.24, J31.3; also elsewhere on the board
TWCK1: J1.32; also elsewhere on the board
TWD1: J1.31; also elsewhere on the board
TXD0: J1.11; also elsewhere on the board
TXD1: J1.9; also elsewhere on the board
URXD: J1.5, J30.3; also elsewhere on the board
UTXD: J1.6, J30.4; also elsewhere on the board
VSSA: J1.33, J5.1, J12.1, J14.1; also elsewhere on the board
V_IN: J4.2 (PM), J11.1, J13.1, J23.1, J25.1, J29.1; also elsewhere on the board
X_MOT_1A: J9.3; also elsewhere on the board
X_MOT_1B: J9.4; also elsewhere on the board
X_MOT_2A: J9.2; also elsewhere on the board
X_MOT_2B: J9.1; also elsewhere on the board
X_STOP_CONN: J9.5; also elsewhere on the board
Y_MOT_1A: J8.3; also elsewhere on the board
Y_MOT_1B: J8.4; also elsewhere on the board
Y_MOT_2A: J8.2; also elsewhere on the board
Y_MOT_2B: J8.1; also elsewhere on the board
Y_STOP_CONN: J8.5; also elsewhere on the board
Z_MOT_1A: J7.3, J15.3; also elsewhere on the board
Z_MOT_1B: J7.4, J15.4; also elsewhere on the board
Z_MOT_2A: J7.2, J15.2; also elsewhere on the board
Z_MOT_2B: J7.1, J15.1; also elsewhere on the board
Z_STOP_CONN: J7.5; also elsewhere on the board

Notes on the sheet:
High Current Screw Term
Common pins

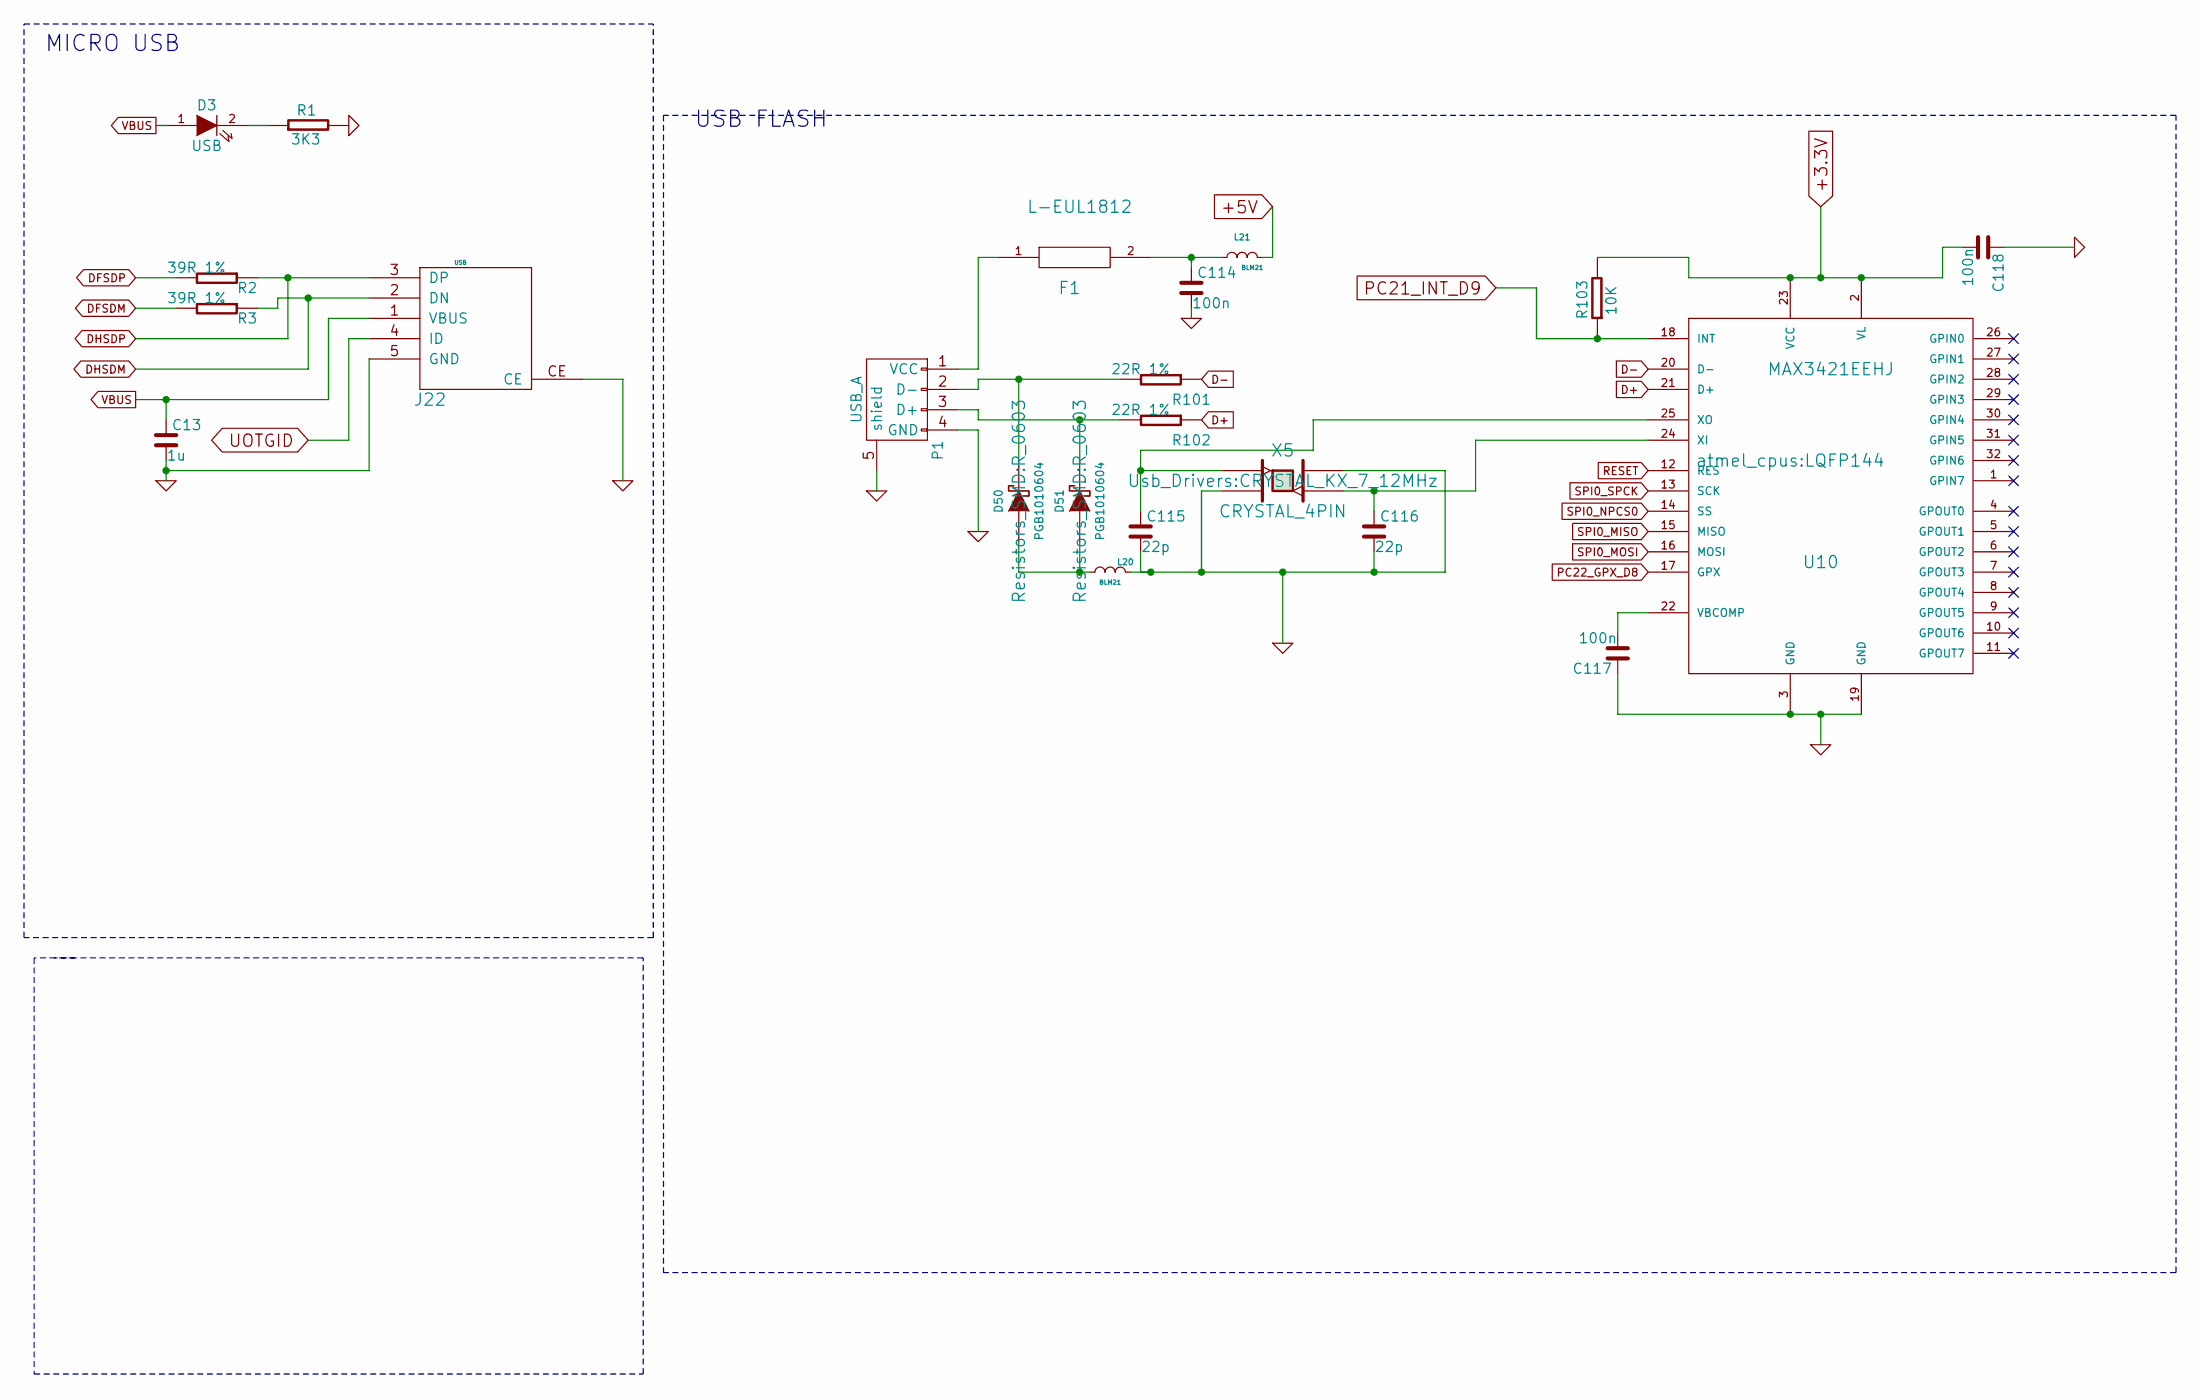
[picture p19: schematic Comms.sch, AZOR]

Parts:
C13: 1u; C_0603
C114, C117, C118: 100n; C_0603
C115, C116: 22p; C_0603
D3: USB; LED_0603
D50, D51: PGB1010604; R_0603
F1: L-EUL1812; L_1812
J22: USB; uUSB_new
L20, L21: BLM21; L_0805
P1: USB_A
R1: 3K3; R_0603
R2, R3: 39R 1%; R_0603
R101, R102: 22R 1%; R_0603
R103: 10K; R_0603
U10: MAX3421EEHJ; LQFP144
X5: CRYSTAL_4PIN; CRYSTAL_KX_7_12MHz

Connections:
+3.3V: C118.2, R103.2, U10.2 (VL), U10.23 (VCC); also elsewhere on the board
+5V: L21.1 (A); also elsewhere on the board
D+: R102.1, U10.21 (D+)
D-: R101.1, U10.20 (D-)
DFSDM: R3.2; also elsewhere on the board
DFSDP: R2.2; also elsewhere on the board
DHSDM: J22.2 (DN), R3.1; also elsewhere on the board
DHSDP: J22.3 (DP), R2.1; also elsewhere on the board
GND: C13.2, C114.2, C115.2, C116.2, C117.1, C118.1, J22.5 (GND), J22.CE, L20.1 (A), P1.4 (GND), P1.5 (shield), R1.2, U10.3 (GND), U10.19 (GND), X5.2, X5.4; also elsewhere on the board
unnamed: C114.1, F1.2, L21.2 (B)
unnamed: C115.1, U10.25 (XO), X5.1
unnamed: C116.1, U10.24 (XI), X5.3
unnamed: C117.2, U10.22 (VBCOMP)
unnamed: D3.2 (K), R1.1
unnamed: D50.1 (A), D51.1 (A), L20.2 (B)
unnamed: D50.2 (K), P1.2 (D-), R101.2
unnamed: D51.2 (K), P1.3 (D+), R102.2
unnamed: F1.1, P1.1 (VCC)
PC21_INT_D9: R103.1, U10.18 (INT); also elsewhere on the board
PC22_GPX_D8: U10.17 (GPX); also elsewhere on the board
RESET: U10.12 (RES); also elsewhere on the board
SPI0_MISO: U10.15 (MISO); also elsewhere on the board
SPI0_MOSI: U10.16 (MOSI); also elsewhere on the board
SPI0_NPCS0: U10.14 (SS); also elsewhere on the board
SPI0_SPCK: U10.13 (SCK); also elsewhere on the board
UOTGID: J22.4 (ID); also elsewhere on the board
VBUS: C13.1, D3.1 (A), J22.1 (VBUS); also elsewhere on the board

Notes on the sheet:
MICRO USB
USB FLASH

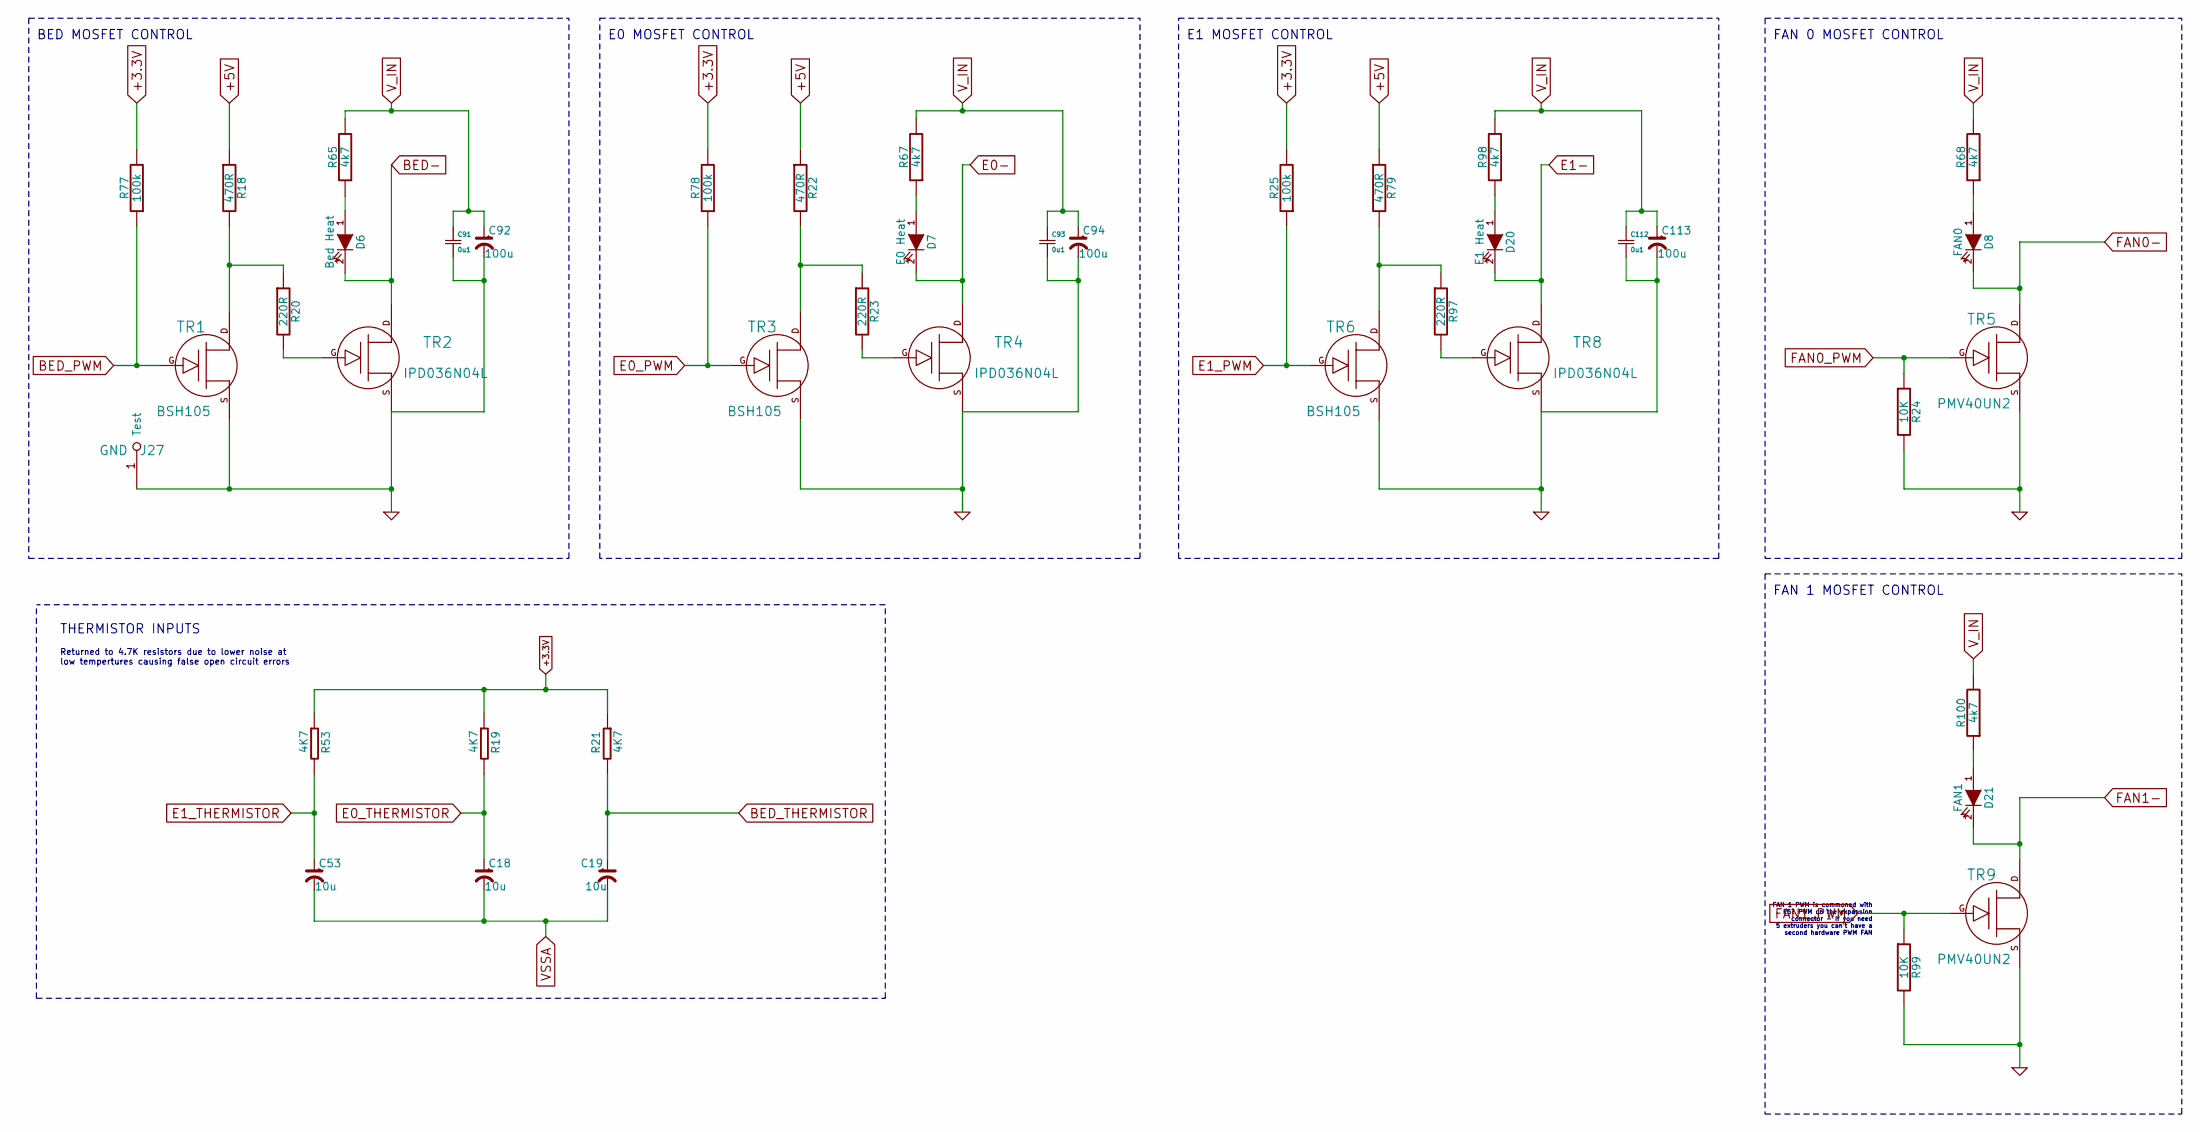
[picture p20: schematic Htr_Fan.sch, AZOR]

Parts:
C18, C19, C53: 10u; C_0805
C91, C93, C112: 0u1; C_0603
C92, C94, C113: 100u; c_elec_6.3x7.7
D6: Bed Heat; LED_0603
D7: E0 Heat; LED_0603
D8: FAN0; LED_0603
D20: E1 Heat; LED_0603
D21: FAN1; LED_0603
J27: GND; Pin_Header_Straight_1x01
R18, R22, R79: 470R; R_0603
R19, R21, R53: 4K7; R_0603
R20, R23, R97: 220R; R_0603
R24, R99: 10K; R_0603
R25, R77, R78: 100k; R_0603
R65, R67, R68, R98, R100: 4k7; R_0603
TR1, TR3, TR6: BSH105; SOT-23
TR2, TR4, TR8: IPD036N04L; D-PAK
TR5, TR9: PMV40UN2; SOT-23

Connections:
+3.3V: R19.1, R21.1, R25.2, R53.1, R77.2, R78.2; also elsewhere on the board
+5V: R18.1, R22.1, R79.1; also elsewhere on the board
BED-: D6.2 (K), TR2.D; also elsewhere on the board
BED_PWM: R77.1, TR1.G; also elsewhere on the board
BED_THERMISTOR: C19.1, R21.2; also elsewhere on the board
E0-: D7.2 (K), TR4.D; also elsewhere on the board
E0_PWM: R78.1, TR3.G; also elsewhere on the board
E0_THERMISTOR: C18.1, R19.2; also elsewhere on the board
E1-: D20.2 (K), TR8.D; also elsewhere on the board
E1_PWM: R25.1, TR6.G; also elsewhere on the board
E1_THERMISTOR: C53.1, R53.2; also elsewhere on the board
FAN0-: D8.2 (K), TR5.D; also elsewhere on the board
FAN0_PWM: R24.1, TR5.G; also elsewhere on the board
FAN1-: D21.2 (K), TR9.D; also elsewhere on the board
FAN1_PWM: R99.1, TR9.G; also elsewhere on the board
GND: C91.2, C92.2, C93.2, C94.2, C112.2, C113.2, J27.1, R24.2, R99.2, TR1.S, TR2.S, TR3.S, TR4.S, TR5.S, TR6.S, TR8.S, TR9.S; also elsewhere on the board
unnamed: D6.1 (A), R65.1
unnamed: D7.1 (A), R67.1
unnamed: D8.1 (A), R68.1
unnamed: D20.1 (A), R98.1
unnamed: D21.1 (A), R100.1
unnamed: R18.2, R20.1, TR1.D
unnamed: R20.2, TR2.G
unnamed: R22.2, R23.1, TR3.D
unnamed: R23.2, TR4.G
unnamed: R79.2, R97.1, TR6.D
unnamed: R97.2, TR8.G
VSSA: C18.2, C19.2, C53.2; also elsewhere on the board
V_IN: C91.1, C92.1, C93.1, C94.1, C112.1, C113.1, R65.2, R67.2, R68.2, R98.2, R100.2; also elsewhere on the board

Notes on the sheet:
Returned to 4.7K resistors due to lower noise at low tempertures causing false open circuit errors
THERMISTOR INPUTS
FAN 0 MOSFET CONTROL
E0 MOSFET CONTROL
BED MOSFET CONTROL
E1 MOSFET CONTROL
FAN 1 MOSFET CONTROL
FAN 1 PWM is commoned with E5? PWM on the expansion connector - If you need 5 extruders you can't have a second hardware PWM FAN

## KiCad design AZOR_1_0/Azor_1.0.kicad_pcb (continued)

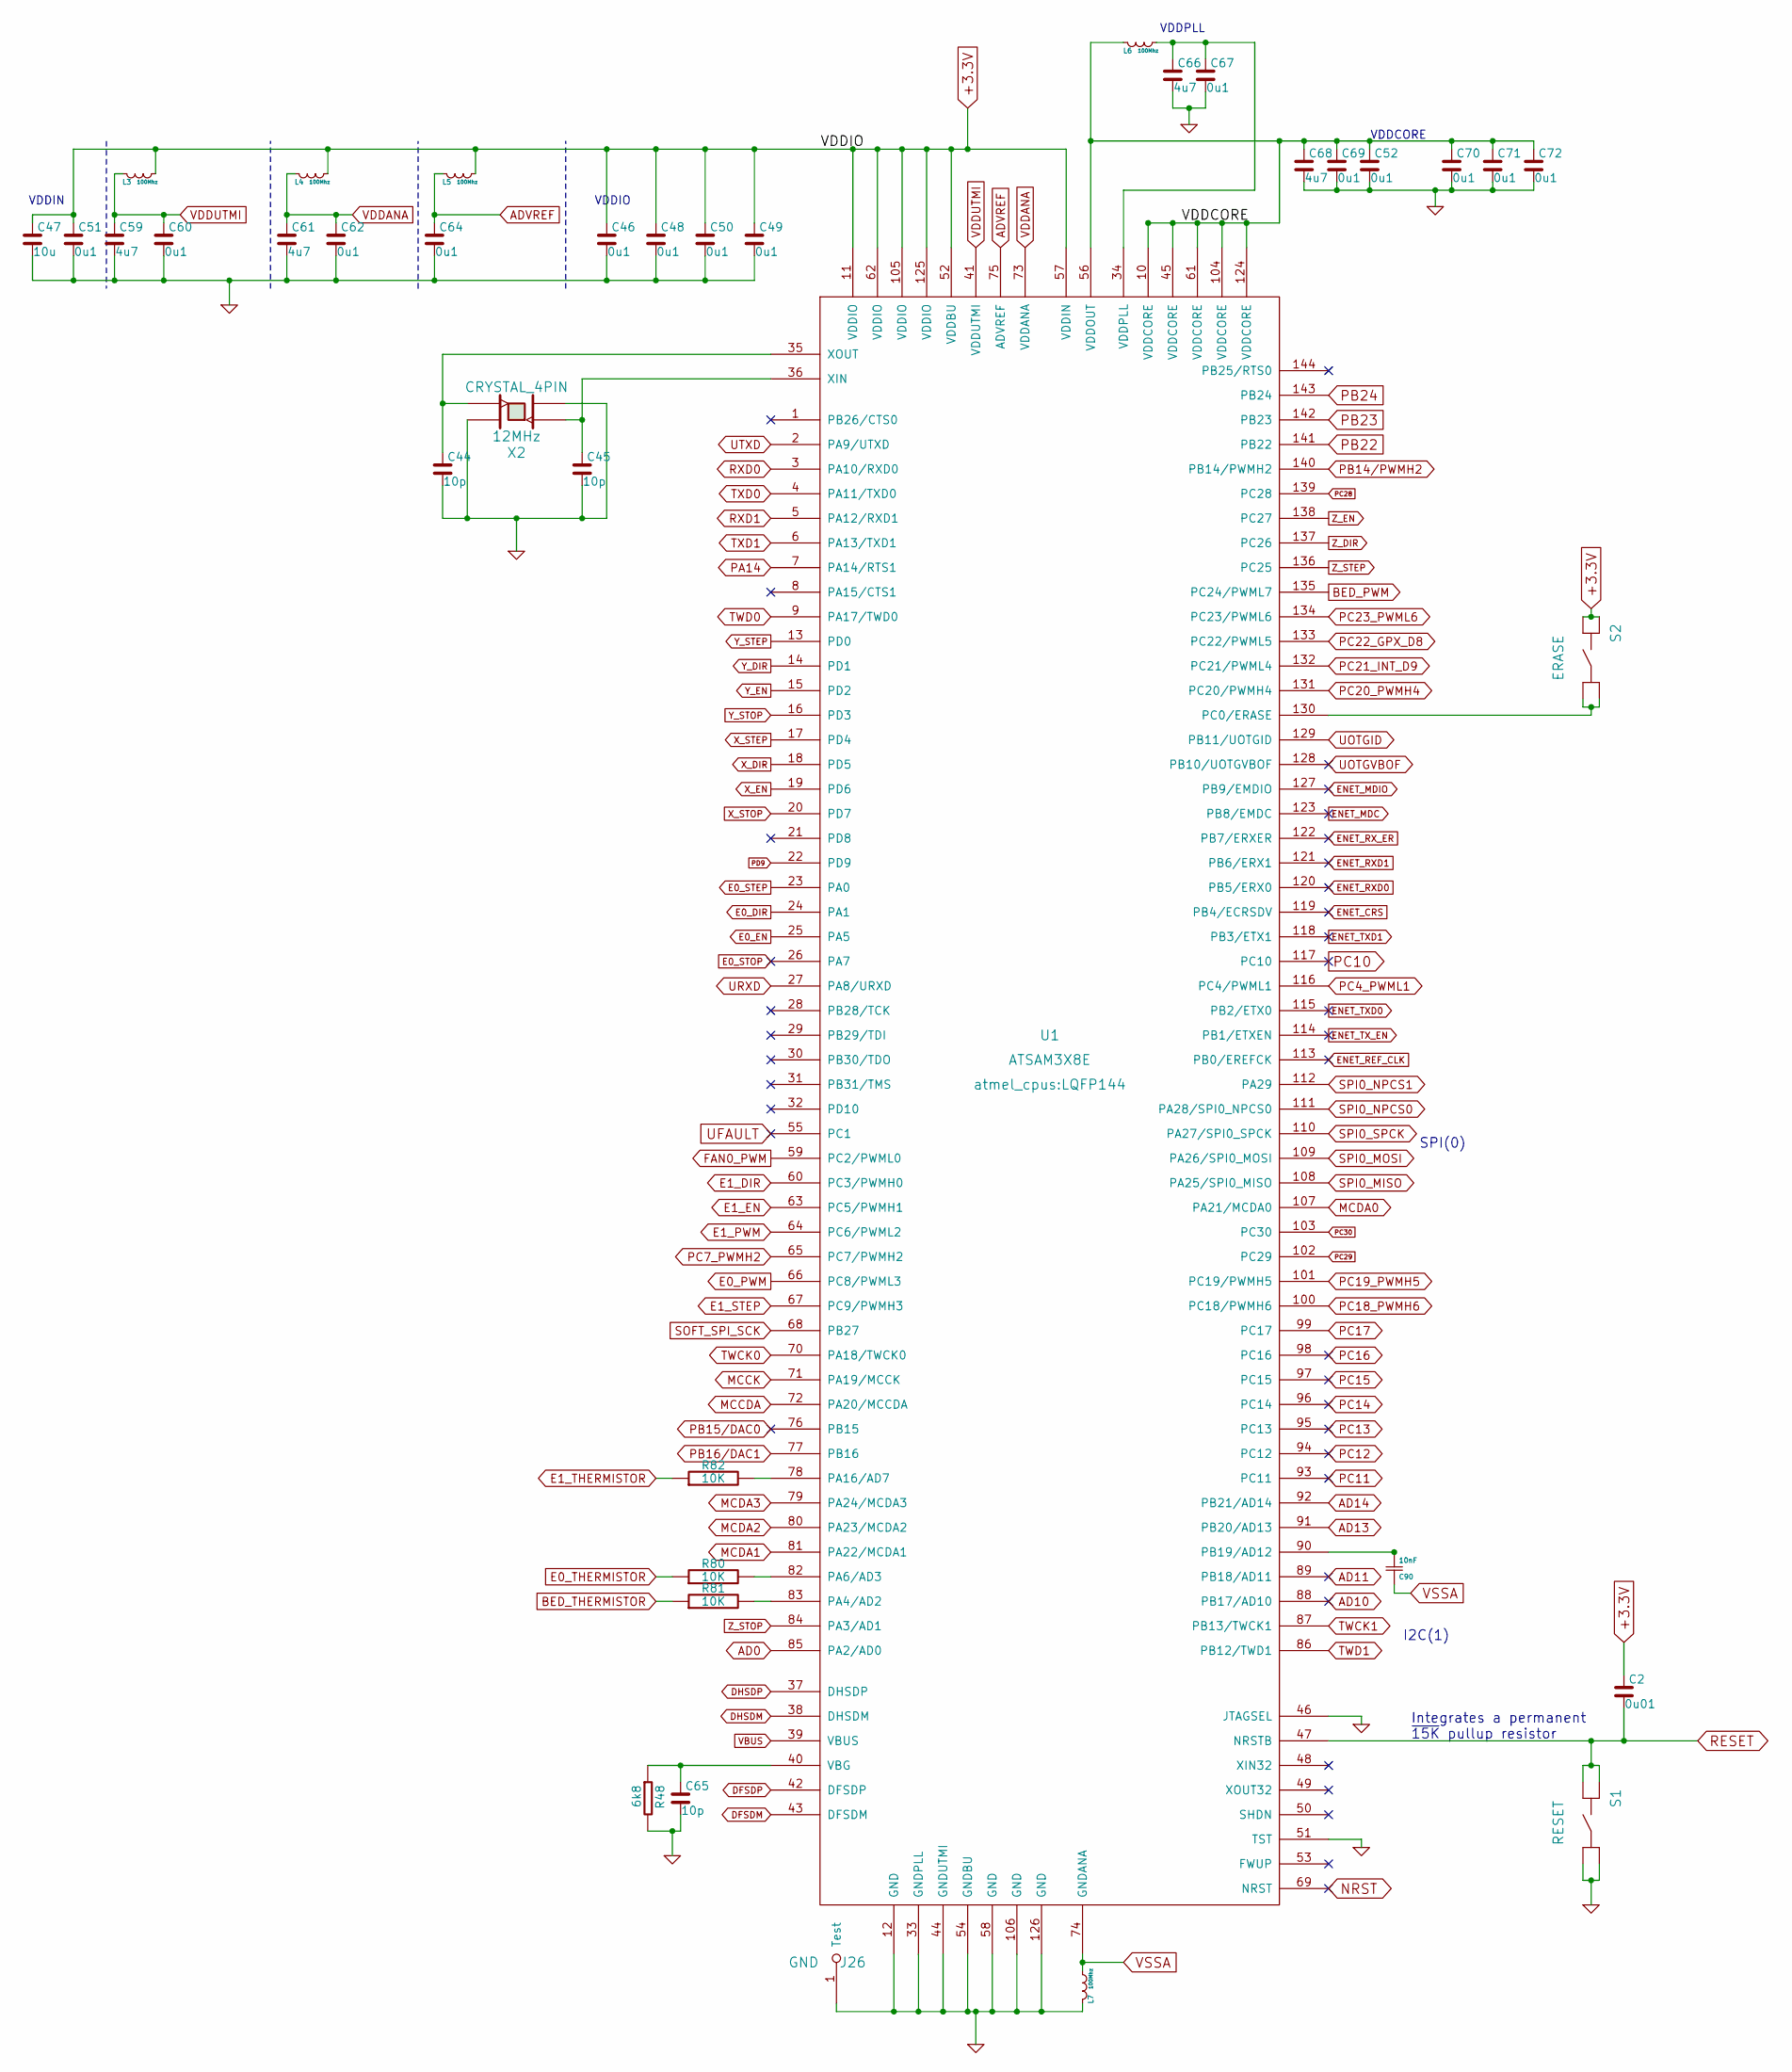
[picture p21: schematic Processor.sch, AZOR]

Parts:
C2: 0u01; C_0603
C44, C45, C65: 10p; C_0603
C46, C48, C49, C50, C51, C52, C60, C62, C64, C67, C69, C70, C71, C72: 0u1; C_0603
C47: 10u; C_0805
C59, C61, C66, C68: 4u7; C_0805
C90: 10nF; C_0603
J26: GND; Pin_Header_Straight_1x01
L3, L4, L5, L6, L7: 100Mhz; R_0603
R48: 6k8; R_0603
R80, R81, R82: 10K; R_0603
S1: RESET; SW_LITTLE_PCB_1
S2: ERASE; SW_LITTLE_PCB_1
U1: ATSAM3X8E; LQFP144
X2: CRYSTAL_4PIN; CRYSTAL_KX_7_12MHz

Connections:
+3.3V: C2.1, C46.1, C47.1, C48.1, C49.1, C50.1, C51.1, L3.2 (B), L4.2 (B), L5.2 (B), S2.3, S2.4, U1.11 (VDDIO), U1.52 (VDDBU), U1.57 (VDDIN), U1.62 (VDDIO), U1.105 (VDDIO), U1.125 (VDDIO); also elsewhere on the board
/Processor/VDDCORE: C52.1, C68.1, C69.1, C70.1, C71.1, C72.1, L6.1 (A), U1.10 (VDDCORE), U1.45 (VDDCORE), U1.56 (VDDOUT), U1.61 (VDDCORE), U1.104 (VDDCORE), U1.124 (VDDCORE)
AD0: U1.85 (PA2/AD0); also elsewhere on the board
AD10: U1.88 (PB17/AD10)
AD11: U1.89 (PB18/AD11)
AD13: U1.91 (PB20/AD13); also elsewhere on the board
AD14: U1.92 (PB21/AD14); also elsewhere on the board
ADVREF: C64.1, L5.1 (A), U1.75 (ADVREF)
BED_PWM: U1.135 (PC24/PWML7); also elsewhere on the board
BED_THERMISTOR: R81.1; also elsewhere on the board
DFSDM: U1.43 (DFSDM); also elsewhere on the board
DFSDP: U1.42 (DFSDP); also elsewhere on the board
DHSDM: U1.38 (DHSDM); also elsewhere on the board
DHSDP: U1.37 (DHSDP); also elsewhere on the board
E0_DIR: U1.24 (PA1); also elsewhere on the board
E0_EN: U1.25 (PA5); also elsewhere on the board
E0_PWM: U1.66 (PC8/PWML3); also elsewhere on the board
E0_STEP: U1.23 (PA0); also elsewhere on the board
E0_STOP: U1.26 (PA7); also elsewhere on the board
E0_THERMISTOR: R80.1; also elsewhere on the board
E1_DIR: U1.60 (PC3/PWMH0); also elsewhere on the board
E1_EN: U1.63 (PC5/PWMH1); also elsewhere on the board
E1_PWM: U1.64 (PC6/PWML2); also elsewhere on the board
E1_STEP: U1.67 (PC9/PWMH3); also elsewhere on the board
E1_THERMISTOR: R82.1; also elsewhere on the board
ENET_CRS: U1.119 (PB4/ECRSDV)
ENET_MDC: U1.123 (PB8/EMDC)
ENET_MDIO: U1.127 (PB9/EMDIO)
ENET_REF_CLK: U1.113 (PB0/EREFCK)
ENET_RXD0: U1.120 (PB5/ERX0)
ENET_RXD1: U1.121 (PB6/ERX1)
ENET_RX_ER: U1.122 (PB7/ERXER)
ENET_TXD0: U1.115 (PB2/ETX0)
ENET_TXD1: U1.118 (PB3/ETX1)
ENET_TX_EN: U1.114 (PB1/ETXEN)
FAN0_PWM: U1.59 (PC2/PWML0); also elsewhere on the board
FAN1_PWM: U1.116 (PC4/PWML1); also elsewhere on the board
GND: C44.2, C45.2, C46.2, C47.2, C48.2, C49.2, C50.2, C51.2, C52.2, C59.2, C60.2, C61.2, C62.2, C64.2, C65.2, C66.2, C67.2, C68.2, C69.2, C70.2, C71.2, C72.2, J26.1, L7.1 (A), R48.2, S1.1, S1.2, U1.12 (GND), U1.33 (GNDPLL), U1.44 (GNDUTMI), U1.46 (JTAGSEL), U1.51 (TST), U1.54 (GNDBU), U1.58 (GND), U1.106 (GND), U1.126 (GND), X2.2, X2.4; also elsewhere on the board
MCCDA: U1.72 (PA20/MCCDA)
MCCK: U1.71 (PA19/MCCK)
MCDA0: U1.107 (PA21/MCDA0)
MCDA1: U1.81 (PA22/MCDA1)
MCDA2: U1.80 (PA23/MCDA2)
MCDA3: U1.79 (PA24/MCDA3)
NRST: U1.69 (NRST)
unnamed: C44.1, U1.35 (XOUT), X2.3
unnamed: C45.1, U1.36 (XIN), X2.1
unnamed: C65.1, R48.1, U1.40 (VBG)
unnamed: C66.1, C67.1, L6.2 (B), U1.34 (VDDPLL)
unnamed: C90.2, U1.90 (PB19/AD12)
unnamed: R80.2, U1.82 (PA6/AD3)
unnamed: R81.2, U1.83 (PA4/AD2)
unnamed: R82.2, U1.78 (PA16/AD7)
unnamed: S2.1, S2.2, U1.130 (PC0/ERASE)
PA14: U1.7 (PA14/RTS1); also elsewhere on the board
PB14/PWMH2: U1.140 (PB14/PWMH2); also elsewhere on the board
PB15/DAC0: U1.76 (PB15)
PB16/DAC1: U1.77 (PB16); also elsewhere on the board
PB22: U1.141 (PB22); also elsewhere on the board
PB23: U1.142 (PB23); also elsewhere on the board
PB24: U1.143 (PB24); also elsewhere on the board
PC7_PWMH2: U1.65 (PC7/PWMH2); also elsewhere on the board
PC10: U1.117 (PC10)
PC11: U1.93 (PC11)
PC12: U1.94 (PC12)
PC13: U1.95 (PC13)
PC14: U1.96 (PC14)
PC15: U1.97 (PC15)
PC16: U1.98 (PC16)
PC17: U1.99 (PC17); also elsewhere on the board
PC18_PWMH6: U1.100 (PC18/PWMH6)
PC19_PWMH5: U1.101 (PC19/PWMH5)
PC20_PWMH4: U1.131 (PC20/PWMH4); also elsewhere on the board
PC21_INT_D9: U1.132 (PC21/PWML4); also elsewhere on the board
PC22_GPX_D8: U1.133 (PC22/PWML5); also elsewhere on the board
PC23_PWML6: U1.134 (PC23/PWML6); also elsewhere on the board
PC28: U1.139 (PC28); also elsewhere on the board
PC29: U1.102 (PC29); also elsewhere on the board
PC30: U1.103 (PC30); also elsewhere on the board
PD9: U1.22 (PD9); also elsewhere on the board
RESET: C2.2, S1.3, S1.4, U1.47 (NRSTB); also elsewhere on the board
RXD0: U1.3 (PA10/RXD0); also elsewhere on the board
RXD1: U1.5 (PA12/RXD1); also elsewhere on the board
SOFT_SPI_SCK: U1.68 (PB27)
SPI0_MISO: U1.108 (PA25/SPI0_MISO); also elsewhere on the board
SPI0_MOSI: U1.109 (PA26/SPI0_MOSI); also elsewhere on the board
SPI0_NPCS0: U1.111 (PA28/SPI0_NPCS0); also elsewhere on the board
SPI0_NPCS1: U1.112 (PA29); also elsewhere on the board
SPI0_SPCK: U1.110 (PA27/SPI0_SPCK); also elsewhere on the board
TWCK0: U1.70 (PA18/TWCK0)
TWCK1: U1.87 (PB13/TWCK1); also elsewhere on the board
TWD0: U1.9 (PA17/TWD0)
TWD1: U1.86 (PB12/TWD1); also elsewhere on the board
TXD0: U1.4 (PA11/TXD0); also elsewhere on the board
TXD1: U1.6 (PA13/TXD1); also elsewhere on the board
UFAULT: U1.55 (PC1)
UOTGID: U1.129 (PB11/UOTGID); also elsewhere on the board
UOTGVBOF: U1.128 (PB10/UOTGVBOF)
URXD: U1.27 (PA8/URXD); also elsewhere on the board
UTXD: U1.2 (PA9/UTXD); also elsewhere on the board
VBUS: U1.39 (VBUS); also elsewhere on the board
VDDANA: C61.1, C62.1, L4.1 (A), U1.73 (VDDANA)
VDDUTMI: C59.1, C60.1, L3.1 (A), U1.41 (VDDUTMI)
VSSA: C90.1, L7.2 (B), U1.74 (GNDANA); also elsewhere on the board
X_DIR: U1.18 (PD5); also elsewhere on the board
X_EN: U1.19 (PD6); also elsewhere on the board
X_STEP: U1.17 (PD4); also elsewhere on the board
X_STOP: U1.20 (PD7); also elsewhere on the board
Y_DIR: U1.14 (PD1); also elsewhere on the board
Y_EN: U1.15 (PD2); also elsewhere on the board
Y_STEP: U1.13 (PD0); also elsewhere on the board
Y_STOP: U1.16 (PD3); also elsewhere on the board
Z_DIR: U1.137 (PC26); also elsewhere on the board
Z_EN: U1.138 (PC27); also elsewhere on the board
Z_STEP: U1.136 (PC25); also elsewhere on the board
Z_STOP: U1.84 (PA3/AD1); also elsewhere on the board

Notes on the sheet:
Integrates a permanent ~15K pullup resistor
SPI(0)
I2C(1)
VDDPLL
VDDCORE
VDDIO
VDDIN

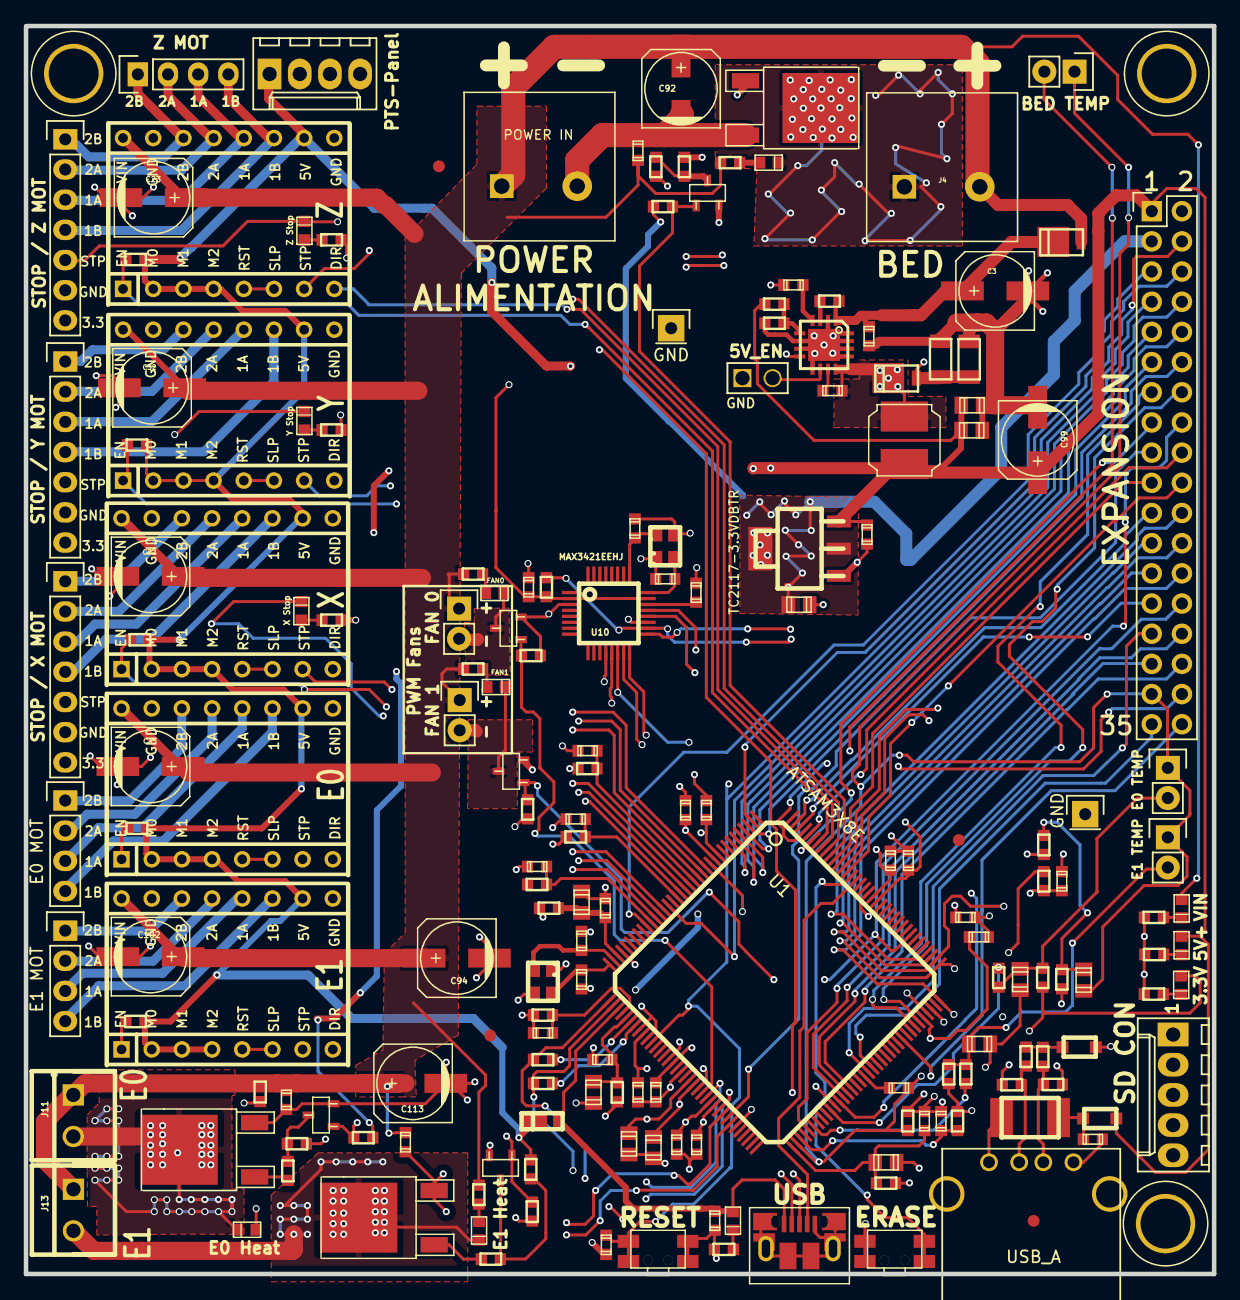
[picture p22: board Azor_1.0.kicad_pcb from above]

Board: 4 copper layers, 100.0 x 105.0 mm, 180 parts (0 on the bottom side), 153 nets.

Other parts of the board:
C43: 0u1; C_0603
Fid: VAL**; Fiducial
Fid#2, Fid#3, Fid#4: VAL**; Fiducial
R59: 100R; R_0603

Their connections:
E0_STOP: C43.1, R59.1; also elsewhere on the board
GND: C43.2; also elsewhere on the board
